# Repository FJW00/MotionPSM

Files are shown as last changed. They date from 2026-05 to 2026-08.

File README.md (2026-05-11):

# MotionPSM

**Mess-System zur Erfassung von Gestängebewegungen an Pflanzenschutzspritzen** auf Basis von Low-Cost GNSS-Modulen (u-blox ZED-F9P, Moving-Base-Konfiguration).

Ursprung: Bachelorarbeit Falk Weigand, Hochschule Weihenstephan-Triesdorf (2025). Weiterentwicklung im Rahmen von FJW Systems.

## Status

- BA-Endstand: Base + 2 Rover, Moving-Base, RTK-fix, Live-Server zur Visualisierung, CSV-Logger mit synchronisierter Zeitstempel-Validierung.
- Aktive Erweiterung (`feature/rover3`): Rover 3 in Fahrtrichtung als geometrische Mittelachsen-Referenz (Base→R3 = Längsachse, R1/R2 als Querauslenkung).
- Zielmeilenstein: DLG-Feldtage 15.06.2026 — System muss 4 Tage am Stück sauber laufen und loggen.

## Struktur

```
MotionPSM/
├── system/
│   ├── pi/                         # Lebender Code (läuft am Raspberry Pi)
│   │   ├── gps_measurement.py      # Threads für Base, Rover1, Rover2 + CSV-Logger
│   │   ├── server.py               # Live-Visualisierung
│   │   └── autostart_schwingung_fw.sh
│   ├── config/
│   │   ├── config.example.json     # Template (echte Datei .gitignored)
│   │   └── f9p_ucenter/            # u-center .txt-Configs für Base/Rover
│   └── analysis/
│       └── Auswertungs_Datei.xlsx  # Prüfprotokoll-Template
├── hardware/                       # STEP/SLDPRT-Modelle Antennenhalterungen, Box
├── documentation/
│   ├── DEVLOG.md                   # Change-Log aller Code-Änderungen
│   ├── 00_initial_meeting.txt      # Auftaktnotizen
│   └── 00_initial_project_vision.md
└── archive/legacy_software/        # Alte Codeversionen, Referenz
```

## Quickstart am Pi

```bash
git clone https://github.com/FJW00/MotionPSM.git
cd MotionPSM
cp system/config/config.example.json system/config/config.json
# COM-Port-IDs eintragen, die zu deiner Hardware passen:
ls /dev/serial/by-id/
# python3-Abhängigkeiten installieren
pip install pyserial pyubx2 pyproj numpy geopy
# Server starten
python3 system/pi/server.py
```

## Hauptmessgröße — Konzept

Bei der bisherigen Setup-Variante (Base + Rover1 + Rover2) wurde das Heading der Base aus deren Eigenbewegung berechnet. Im Stillstand fällt diese Referenz aus, und die Mittellinie ist verrauscht.

Mit Rover 3 vorne in Fahrtrichtung wird der Vektor Base→R3 zur **harten geometrischen Längsachse** der Maschine. Rover 1 und Rover 2 werden senkrecht auf diese Achse projiziert; Ergebnis ist die Querauslenkung des Gestänges in cm — auch im Stillstand stabil.

Details: siehe `documentation/DEVLOG.md` ab Eintrag "Rover3 Mittelachsen-Projektion".

## Verwandte Doku

- `documentation/DEVLOG.md` — alle Änderungen mit Datum + Begründung + offenen Tests
- `archive/legacy_software/` — Vor-Erweiterungs-Codestände (Heading_F9P_thread, alte PI/USB-Varianten)

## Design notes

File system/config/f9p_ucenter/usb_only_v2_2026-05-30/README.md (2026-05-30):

# USB-only Configs für ZED-F9P (Stand 2026-05-30)

## Zweck
Diese Configs lösen das 5-Hz-Problem auf den Rovern: ZED-F9P-Module wurden intern
gedrosselt weil NMEA-Messages auf ALLEN 5 Ports (I2C + UART1 + UART2 + USB + SPI)
gleichzeitig ausgegeben wurden. Bei 10 Hz Mess-Rate × 18 Output-Operationen
landeten effektiv nur 5 Hz NAV-RELPOSNED auf USB.

## Was geändert wurde
Für jedes Modul gegenüber Original:
- USB-Outputs für NMEA-GGA, NMEA-RMC, NMEA-VTG, NAV-RELPOSNED, NAV-PVT: **bleiben aktiv (= 1)**
- I2C, UART1, UART2, SPI Outputs für UBX/NMEA: **auf 0 gesetzt**
- **RTCM-Settings unverändert** (Base UART2-RTCM-Output → Rover Moving-Base-RTK weiterhin funktional)
- CFG-RATE-MEAS = 100 ms (10 Hz) und CFG-RATE-NAV = 1 unverändert

## Wie die korrekten Item-IDs ermittelt wurden
Wichtig: die Item-IDs für jede UBX/NMEA-Message + Port wurden direkt aus
`pyubx2.UBX_CONFIG_DATABASE` extrahiert — autoritative u-blox Doku, identisch
mit der Library die auch der MotionPSM-Logger nutzt.

Ein erster Versuch (Ordner `usb_only_2026-05-25` — wurde verworfen, nicht im Repo)
hatte geschätzte Item-IDs für NAV-RELPOSNED genutzt (offset 0x8C statt 0x8D),
dadurch landete USB auf 0 statt UART2 — Pi konnte kein NAV-RELPOSNED lesen.
Daraus die Lektion: bei UBX-Config-Modifikationen immer pyubx2-DB als Quelle.

## Anwendung in u-center
1. Modul per USB an Laptop
2. Tools → Receiver Configuration → Browse → `..._USBonly_v2.txt`
3. Transfer file → GNSS
4. View → Configuration View → CFG → Save current configuration (BBR + Flash) → Send
5. Disconnect, nächstes Modul

## Verifikation
Auf dem Pi mit pyubx2-Hz-Test:
```bash
sudo systemctl stop motionpsm 2>/dev/null
for port in usb-B_B-if00 usb-R_1-if00 usb-R_2-if00 usb-R_3-if00; do
  echo -n "$port: "
  timeout 5 python3 -c "
import serial,pyubx2,time
s=serial.Serial('/dev/serial/by-id/$port')
u=pyubx2.UBXReader(s,validate=0)
n=0; e=time.time()+5
while time.time()<e:
    try:
        _,p=u.read()
        if p and p.identity in ('NAV-RELPOSNED','NAV-PVT'): n+=1
    except: pass
print(f'{n/5:.1f} Hz')"
done
```
Erwartung: alle Module 10.0 Hz auf NAV-RELPOSNED (Rover) bzw. NAV-PVT (Base).

## Hinweise
- Base-Config liegt vor, ist aber bei Stand 2026-05-30 **noch nicht** geflasht
  (Base war nie der 5-Hz-Engpass, sie lief schon bei vollen 10 Hz).
  Sauberkeitshalber kann sie post-DLG mit dieser Config nachgeflasht werden.
- NAV-PVT USB ist bei den Rovern bewusst aus (war auch in Original-Configs schon so);
  der Logger nutzt NAV-RELPOSNED + die 3 NMEA-Messages.

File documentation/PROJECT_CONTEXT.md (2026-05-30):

# PROJECT_CONTEXT — MotionPSM / FJW Systems

**Diese Datei ist das Cold-Start-Briefing für jede neue Cowork-Session.**
Falk sagt zu Beginn: "Lies erst `documentation/PROJECT_CONTEXT.md`" — und du bist sofort drin.

Stand: 2026-05-30.

---

## Wer und Was

**Person:** Falk-Jakob Weigand, HSWT-Absolvent (Bachelor 2025). Gründer **FJW Systems** (Einzelunternehmen, **angemeldet 20.05.2026** über Bayern-Serviceportal, nicht im Handelsregister eingetragen, Regelbesteuerung). Hauptberuf parallel: Vollzeit-Job Mo–Fr 7–16 Uhr. Codet abends + Wochenenden.

**Gewerbe-Tätigkeitsbeschreibung (Stand 20.05.2026):**

> Entwicklung, Herstellung, Vertrieb, Vermietung und Integration von Mess-, Sensor-, Automatisierungs- und Assistenzsystemen für die Land- und Forstwirtschaft sowie industrielle Anwendungen; Entwicklung, Vertrieb und Betrieb von GNSS-, RTK-, Telemetrie-, IoT- und datenbasierten Systemen; Erbringung von Mess-, Vermessungs-, Analyse- und Monitoringdienstleistungen mittels GNSS-, Sensor-, Drohnen- und Kameratechnologie einschließlich Luftbildauswertung, Vegetationsanalyse sowie Erstellung von Applikations- und Bewirtschaftungskarten für Düngung, Pflanzenschutz und teilflächenspezifische Landwirtschaft; Entwicklung von Hard- und Software, Embedded Systems sowie Datenverarbeitungs- und Cloudlösungen einschließlich Anwendungen im Bereich künstlicher Intelligenz, Automatisierung und Digitalisierung; technische Beratung, Schulung sowie Forschungs- und Entwicklungsdienstleistungen in den genannten Bereichen; Entwicklung, Herstellung und Nachrüstung elektronischer, mechanischer und technischer Komponenten, Sonderlösungen und Prototypen für landwirtschaftliche, kommunale und industrielle Anwendungen; Handel mit Zubehör, Ersatzteilen, elektronischen Baugruppen und technischen Komponenten.

**Produkt:** **MotionPSM** — Low-Cost GNSS-basiertes Mess-System zur Erfassung der Gestängebewegungen von Pflanzenschutzspritzen. Soll Landwirten / Maschinenherstellern eine günstige Möglichkeit geben, Boom-Schwingungen quantitativ zu erfassen.

**Kontakt:**
- Email: falkweigand1304@gmail.com / info@fjw-systems.com
- Domain: fjw-systems.de, fjw-systems.com — **Onepager LIVE seit 30.05.2026** (Impressum + Datenschutz inkl.)
- Firmensitz: Steinig 1a, 97956 Werbach

---

## Hardware-Architektur

- **Base** (u-blox ZED-F9P, C099 Board): zentrale RTK-Basis. **MUSS auf einem starren Rahmen sitzen, NICHT am Gestänge** (sonst werden Rover-Schwingungen systematisch verfälscht — Erkenntnis aus 17.05.-Test). Geeignet: Schlepperdach/Kabine ODER Spritzen-Chassis (sofern lang genug für ~3 m Baseline Base→R3 — Falk's Spritze hat das, getestet 22.05./30.05.). Maximale Sky-View. Sendet RTCM-Korrekturen via UART2 an die Rover.
- **Rover 1** (ZED-F9P): **links** am Gestänge montiert (vom Fahrer aus gesehen).
- **Rover 2** (ZED-F9P): **rechts** am Gestänge.
- **Rover 3** (ZED-F9P): **vorne in Fahrtrichtung am Schlepper** (NICHT am Gestänge), definiert die Längsachse Base→R3.
- **Raspberry Pi 5 (8 GB)**: zentrale Steuerung (seit Ende 2025 von Pi 4 upgegradet). Liest alle Module über USB ein (`/dev/serial/by-id/...`), läuft Flask-Server zur Live-Anzeige + CSV-Logger.
  - **Active Cooler** (GeeekPi Armor Lite V5) seit 30.05.: max. 50°C bei 32°C Außentemperatur + Sonne — Throttling-Problem (87.8°C in alter Box) gelöst.
  - **Neue ASA-Box** mit Belüftungsschlitzen + Heatsink-Aussparung.
- **Antennenhalter**: STEP-Files in `hardware/f9p/`. Falks Eigenkonstruktion mit Kamera-Rohrklemmen — vibrationsfest, wird übernommen für alle Aufbauten.

**RTK-Modus:** Moving-Base. Jeder Rover bekommt RTCM von der Base und liefert `relPosNED` (Position relativ zur Base) mit RTK-Genauigkeit (~cm).

**COM-Port-IDs (echte Werte sind in `system/config/config.json` lokal am Pi, .gitignored):**
- Base: `DBTFR0K9`
- Rover 1: `DBTIHI5H`
- Rover 2: `DBTLN7UC`
- Rover 3: noch nicht festgehalten — beim ersten Anstecken aus `ls /dev/serial/by-id/` ablesen

---

## Mess-Konzept

### Bisher (vor Rover 3)
- Heading der Base aus Eigenbewegung berechnet → verrauscht + nicht stillstandsfähig.
- Moving-Average als Notbehelf für Mittellinien-Stabilisierung.

### Neu mit Rover 3
- Vektor Base→R3 **ist** die geometrische Längsachse der Maschine (auch im Stillstand stabil).
- Zwei parallele Auswertungsvarianten:
  - **Variante A (Hauptmetrik):** R1, R2 senkrecht auf Achse projiziert → `lateral_offset_cm` (signed). Konvention: **links = positiv**, rechts = negativ.
  - **Variante B (Vergleich):** Differenzvektoren R3→R1 und R3→R2 → Distanz + Heading, direkt aus relPosNED-Diff.
- Beides wird ins CSV geloggt (`VarA_*` und `VarB_*` Spalten am Ende).

### CSV-Layout (81 Spalten, Stand 17.05. — unverändert seit Tare/Filter-Iteration)
1. R1 (17 Spalten) — Heading-Stats, Position, Quality
2. R2 (17)
3. R3 (17)
4. Base (8) — Position, Heading, Speed
5. Berechnungen Variante A + B + Achsen-Info + Total (11)
6. Filtered Spalten (6) — Moving-Average longitudinal + Symmetric/Asymmetric Yaw raw+filtered (siehe config.json `FILTER_WINDOW_S`, default 0.2 s)
7. Tare-bereinigte Spalten (5) — VarA_R*_longitudinal/lateral_tared_cm + Tare_set_at

### Hauptmetriken
- **`longitudinal_cm`** = Vor-/Rück-Auslenkung von R1/R2 entlang Fahrtrichtung. + = vorne, − = hinten. **Das ist die Schwingungs-Metrik.**
- **`lateral_cm`** = Seitlicher Abstand zur Längsachse. ≈ Gestängehalbe, fast konstant.
- **`Symmetric Yaw`** = (R2_long − R1_long) / 2. Rotation des Gestänges um die Mittelachse.
- **`Asymmetric Yaw`** = (R1_long + R2_long) / 2. Translation des Gestänges (vor/zurück).
- Mathematik ist **rotationsinvariant gegen Maschinen-Heading** (Beweis im DEVLOG 17.05.).

### UI-Funktionen
- **Tare-Button "⌖ Set Zero"** oben rechts (links neben Toggle): speichert aktuelle Werte als Nullpunkt. CSV bekommt zusätzliche `*_tared_cm`-Spalten. Tare-Status mit Clear-`×` daneben.
- **Toggle "Smoothed | Raw"** oben rechts: schaltet Anzeige zwischen gefilterten und rohen Werten. CSV bekommt immer beides. Persistent in localStorage.
- **Set Zero VOR jeder Messung drücken** (nach Aufbau, Maschine still) → Schwingungs-Auswertung relativ zur Ausgangslage.

---

## Repository-Struktur

```
FJW_Schwingung/                         <- lokaler Master-Ordner
├── MotionPSM_repo/                     <- Git-Repo (github.com/FJW00/MotionPSM)
│   ├── system/
│   │   ├── pi/                         <- Lebender Code
│   │   │   ├── gps_measurement.py      <- Threads, Logger, CSV
│   │   │   ├── geometry.py             <- Mittelachsen-Projektion (Var A) + Diff-Vektoren (Var B)
│   │   │   ├── server.py               <- Flask + HTML-Frontend
│   │   │   └── autostart_schwingung_fw.sh
│   │   ├── config/
│   │   │   ├── config.example.json     <- Template (im Repo)
│   │   │   ├── config.json             <- echte COM-Port-IDs (.gitignored, nur lokal/am Pi)
│   │   │   └── f9p_ucenter/usb_only_v2_2026-05-30/   <- Aktive u-blox Configs (USB-only Outputs, 10 Hz)
│   │   └── analysis/
│   │       └── Auswertungs_Datei.xlsx  <- Excel-Template Prüfprotokoll
│   ├── hardware/                       <- STEP/SLDPRT-Modelle Halter, Box
│   ├── documentation/
│   │   ├── DEVLOG.md                   <- Detail-Log aller Änderungen
│   │   ├── PROJECT_CONTEXT.md          <- DIESE Datei
│   │   ├── 00_initial_meeting.txt
│   │   └── 00_initial_project_vision.md
│   └── archive/legacy_software/        <- alte Code-Stände (Heading_F9P_thread, alte PI/USB-Varianten)
│
├── business/                           <- LOKAL, nie Git
│   ├── branding/                       (Logos)
│   ├── gruendung/{exist,hswt,gewerbeanmeldung}/
│   ├── finanzen/{kalkulationen,rechnungen,steuer}/
│   ├── recht/{ndas,eigentumserklärung}/
│   ├── kunden/feldtage_2026/
│   ├── vorlagen/                       <- Brief/Word-Templates (für Dokumente nutzen)
│   └── website/
│
├── data/                               <- LOKAL, große Files
│   ├── ba_messungen/                   (alte CSVs, Auswertungen)
│   ├── validierung_2025-12/            (Seilzug- und Kamera-Validierung)
│   └── literatur/                      (u-blox-Docs + Fremdliteratur PDFs)
│
├── BA_Abgabe/                          <- Bachelorarbeit, eingefroren read-only
│
└── archive/
    ├── 2026-05-11_full_backup/         (1:1 Backup vor Repo-Reset)
    └── _legacy_empty/                  (leere Original-Ordner, macOS rmdir blockt)
```

---

## Branches

- `main` — **Production-Stand** (54d1dd4): USB-only Configs v2 + Sleep-Fix + alle DEVLOG-Einträge.
- `refactor/logger-itow-dict` — **in Test** (a0fb3f3): Refactor C — iTOW-Dict-Logger statt 4 unsync'd Queues. Behebt die 38%-Sample-Drop-Race in der alten Architektur. Bench-Test am Pi am 31.05.2026, bei Erfolg Merge nach main.
- `refactor/cleanup` — historischer Branch (Stufe-2-Refactor), unverändert seit Mai
- `feature/rover3` — gelöscht (komplett in main gemerged, 30.05.)

---

## Termine + Meilensteine — laufender Fortschritt

| Datum | Was | Status |
|---|---|---|
| 14.05. | Bench-Test Rover 3 | ✅ |
| 15.–17.05. | Feldtest + Iterationen, UI-Refactor, Filter, Tare | ✅ |
| 19.05. | Steuerberater-Termin | ✅ |
| 20.05. | **Gewerbeanmeldung** Bayern-Serviceportal | ✅ Gründungstag |
| 22.05. | Testfahrt mit Tare: 10 cm Stand-Auslenkung exakt gemessen | ✅ (Geometrie + Tare validiert) |
| 22.05. | Pi-Thermal-Problem entdeckt (87.8°C → Sample-Lücken) | ✅ diagnostiziert |
| 23.05. | Active Cooler bestellt (GeeekPi Armor Lite V5) | ✅ |
| 24./25.05. | Generalprobe-Wochenende mit neuer Box + Cooler (50°C bei 32°C/Sonne) | ✅ |
| 25.05. | 5-Hz-Problem entdeckt (CFG-RATE OK aber NMEA-Multicast drosselt F9P) | ✅ diagnostiziert |
| 26.05. | USB-only Configs v1 — fehlerhaft (off-by-one Item-IDs) | ✅ verworfen |
| 30.05. | USB-only Configs v2 mit pyubx2-DB → 10 Hz auf allen Modulen | ✅ commit 54d1dd4 |
| 30.05. | Hof-Test: 10/20 cm Tare-Auslenkung exakt gemessen | ✅ Geometrie 2× validiert |
| 30.05. | Logger-Refactor C (iTOW-Dict) implementiert | ✅ commit a0fb3f3 (Branch) |
| 30.05. | Grundplatten Base + R3 bestellt | ✅ |
| 30.05. | feature/rover3 → main gemerged, Repo aufgeräumt | ✅ |
| 30.05. | **fjw-systems.de LIVE** (Impressum + Datenschutz) | ✅ 🎉 |
| **31.05. 09:00** | **Bench-Test Refactor C am Pi** | 📅 scheduled |
| Anfang Juni | Echte Testfahrt mit Refactor + USB-only + Hardware-Updates | ⏳ |
| Anfang Juni | ZTE-WLAN-Port-Forwarding fixen (Tablet↔Pi externer Zugang) | ⏳ |
| Anfang Juni | Autostart am Pi aktivieren (`install_autostart.sh`) | ⏳ |
| 06./07.06. | Reserve-WE für letzte Fahrtests + Bug-Fix | herabgestuft |
| Vor 15.06. | Geschäftskonto eröffnet | ⏳ (nicht zwingend) |
| **15.–18.06.** | **DLG-Feldtage Bernburg** — erste öffentliche Demo | Hauptevent |
| Juli 2026 | GitHub-PAT von Classic auf Fine-grained rotieren (läuft August aus) | 📅 |
| Nach 15.06. | RTCM-Löten, Cloudflare-Tunnel (`measure1.fjw-systems.com`), Pi-User/Hostname-Migration | später |

---

## Konventionen / Falk's Präferenzen

- **Sprache:** Deutsch.
- **Tonalität:** pragmatisch, direkt, keine Floskeln.
- **Vor destruktiven Änderungen fragen** ("wenn du änderungen machst frage mich").
- **DEVLOG parallel führen** — jeder Code-Change kriegt einen Eintrag mit Was/Warum/Test offen/Risiko.
- **Vertrauliche Daten niemals ins Repo:** echte HW-IDs, NDAs, Kalkulationen, Förderanträge gehören in `business/` oder werden sanitisiert.
- **Calendar:** noch nicht freigeschaltet. Steuerberater (Freund) kümmert sich Falk selbst.

---

## Tech-Stack

- **Python 3** (Pi 5, venv): Flask, pyserial, pyubx2, pyproj, numpy, geopy
- **Frontend:** Vanilla HTML + Chart.js (CDN)
- **GNSS:** u-blox ZED-F9P, Moving-Base, **10 Hz** (effektiv erreicht nach USB-only Configs v2 + Refactor C). Baudrate 460800 auf USB.
- **LTE-Konnektivität:** ZTE-WLAN-Stick + Thingsmobile IoT-SIM in der Box (für DLG-Stand-WLAN; Port-Forwarding für externen Zugriff noch zu fixen)
- **Datenformat:** CSV mit `;`-Separator und `,`-Decimal (Excel-DE-kompatibel)

---

## Offene Punkte / Ideen für später

**Vor DLG (15.06.):**
- **Bench-Test Refactor C** (31.05. 09:00 scheduled): wenn >95% iTOW-Lücken bei 100 ms → Merge nach main
- **ZTE-WLAN-Port-Forwarding**: WLAN-Verbindung Tablet↔Pi funktioniert, aber externer Port (Remote-Zugriff aufs Frontend) klemmt. ZTE-Admin-Interface checken.
- **Autostart am Pi aktivieren** (`bash system/pi/install_autostart.sh`) — Code liegt schon, war für "nach Generalprobe" geplant, jetzt der richtige Moment
- **Echte Testfahrt** mit allen Updates zusammen (Refactor C + USB-only + Box + Cooler)

**Nach DLG:**
- **Remote-Zugriff `measure1.fjw-systems.com`** — Cloudflare-Tunnel (braucht Nameserver-Umstellung weg von Strato) ODER Pi-eigener WLAN-AP als Fallback
- **Pi-User + Hostname migrieren** — derzeit User `ba_weigand`, Hostname `BA_Weigand` aus der BA-Zeit. Sauberer wäre `motionpsm` + `motionpsm-pi-01`
- **Base-Config mit USBonly_v2 nachflashen** — war beim 5-Hz-Fix nicht zwingend (Base war nicht der Engpass), nur für Konsistenz
- **NumSV / HDOP / accHeading** im Frontend zeigen
- **GitHub-PAT** von Classic auf Fine-grained umstellen (Sicherheit)
- **Mail-/Kalender-MCP** (Google Workspace) — Cowork-Connector

## Hardware-Detail: udev-Regeln am Pi

Falk hat udev-Regeln eingerichtet, die die F9P-Module unter festen Kurz-Namen mappen (Pi-User noch `ba_weigand` aus BA-Zeit, Migration post-DLG geplant):
- `/dev/serial/by-id/usb-B_B-if00` (Base)
- `/dev/serial/by-id/usb-R_1-if00` (Rover 1, links)
- `/dev/serial/by-id/usb-R_2-if00` (Rover 2, rechts)
- `/dev/serial/by-id/usb-R_3-if00` (Rover 3, vorne)

Diese Namen kommen in seine echte `system/config/config.json` (.gitignored). Die `config.example.json` im Repo hat die langen Standard-IDs als Platzhalter.

---

## Wie ich (Claude) helfe

- Code-Änderungen: erst Diff zeigen, dann committen, dann pushen.
- Bei langen Tasks: TodoList + Backup vor destruktiven Schritten.
- Push erfolgt via PAT (im August 2026 auslaufend); Token bei Bedarf erneuern.
- Branches: pro Feature ein eigener Branch, Push auf GitHub, Merge per Falk-Entscheidung.
- Bei neuer Session: bitte dieses File lesen, dann letzten DEVLOG-Eintrag, dann `git log --oneline -10` für aktuellen Repo-Stand.

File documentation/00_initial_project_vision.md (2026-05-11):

# BA_Weigand

# Erfassung von Schwingungen im Spritzengestänge durch Low-Cost Messsystem

## Projektübersicht
Dieses Projekt zielt darauf ab, ein kostengünstiges und modulares System zu entwickeln, das die Schwingungen von Spritzgestängen in der Landwirtschaft erfasst. Die erfassten Daten sollen gespeichert und zur Optimierung von Precision-Farming-Anwendungen genutzt werden.

## Zielsetzung
- **Modularität**: Flexible Anpassung an verschiedene Spritzgestänge und Sensoren.
- **Datenerfassung und -speicherung**: Aufzeichnung der Messdaten auf einer SD-Karte.
- **Analyse der Schwingungen**: Berechnung der Schwingungsdaten relativ zur Gesamtbreite des Gestänges.

## Systemansätze
Es werden drei mögliche Ansätze untersucht, wobei die ersten beiden priorisiert werden:

1. **GNSS-Modul (F9P)**:
   - Verwendung von 3-4 GNSS-Empfängern:
     - Zwei Empfänger in der Mitte des Gestänges zur Bestimmung von Heading und Offset.
     - Jeweils ein Empfänger an den Enden zur Detektion der Schwingungen.
   - **Offene Fragen**: Konfiguration und serielle Kommunikation.

2. **Beschleunigungssensoren**:
   - Platzierung von Sensoren an den Enden und in der Mitte des Gestänges.
   - Messung der Beschleunigungen zur Analyse der Schwingungen.
   - **Offene Fragen**: Nutzung von Interrupts oder Dataloggern.

3. **Kamerabasierte Lösung (OpenCV)**:
   - Kamera in der Mitte des Gestänges, die zwei markierte Bälle an den Enden verfolgt.
   - Analyse der Ballbewegung zur Erkennung von Schwingungen.
   - **Herausforderung**: Hoher Umsetzungsaufwand, daher aktuell nicht priorisiert.

## Anforderungen
- **Modularität**: Das System muss einfach erweiterbar sein.
- **Datenaufzeichnung**: Speicherung aller relevanten Daten auf einer SD-Karte.
- **Prozentuale Analyse**: Berechnung der Schwingungen relativ zur Breite des Gestänges.

## Vorgehensweise
1. **Entwicklung der Testsysteme**:
   - Umsetzung der Ansätze mit GNSS-Modulen und Beschleunigungssensoren.
2. **Validierung und Tests**:
   - Durchführung von Tests an der Landwirtschaftlichen Lehranstalt (LLA) mit Spritzgestängen verschiedener Hersteller.
   - Kalibrierung der Sensoren durch Vergleich mit Bodenmessungen (z. B. Meterstab oder Skala).

## Offene Fragen
Während des Projekts sind folgende Punkte zu klären:
- Wie können Korrekturdaten effizient verteilt werden?
- Ist eine Berechnung über den Dopplereffekt sinnvoll?
- Welche bestehenden Systeme können als Referenz dienen?
- Welcher Ansatz ist am zuverlässigsten, kostengünstigsten und genauesten?

## Motivation
Das Projekt unterstützt die Weiterentwicklung des Precision Farming, indem es präzisere Daten für die Optimierung von Spritzgestängen liefert. Dies trägt zur Effizienzsteigerung und Ressourcenschonung in der Landwirtschaft bei.

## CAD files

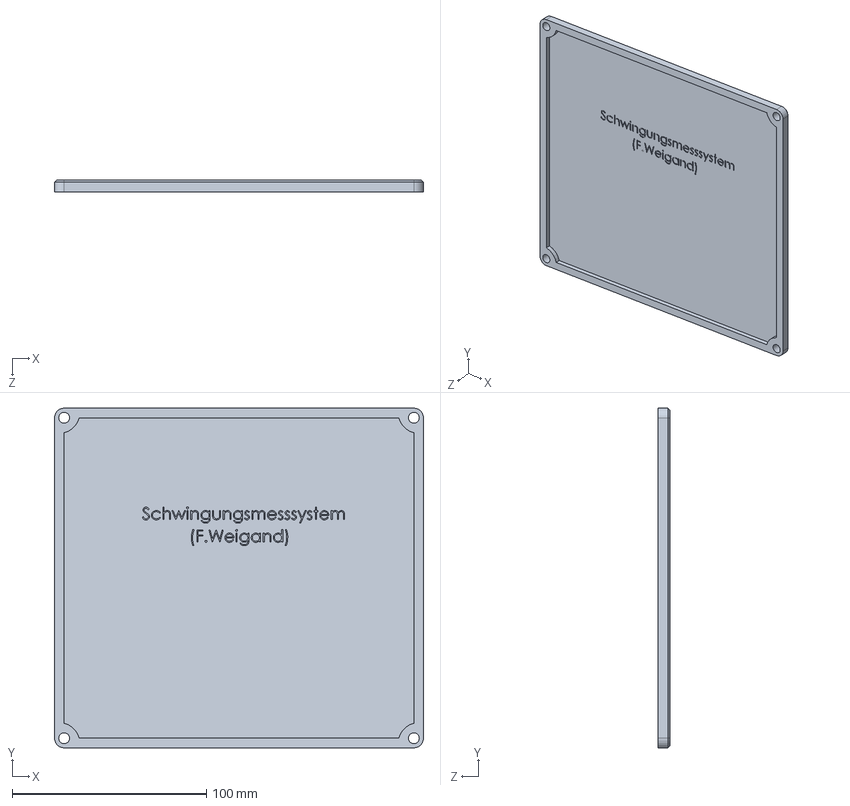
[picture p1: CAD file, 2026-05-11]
hardware/f9p/C099-F9P/Deckel.SLDPRT
190.0 x 175.0 x 6.00 mm

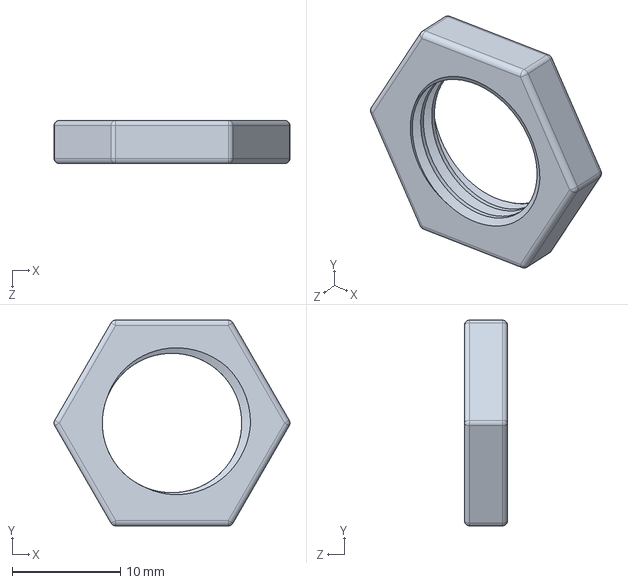
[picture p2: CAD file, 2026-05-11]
hardware/f9p/Mutter_M16x1,5.STEP
21.8 x 19.0 x 4.00 mm

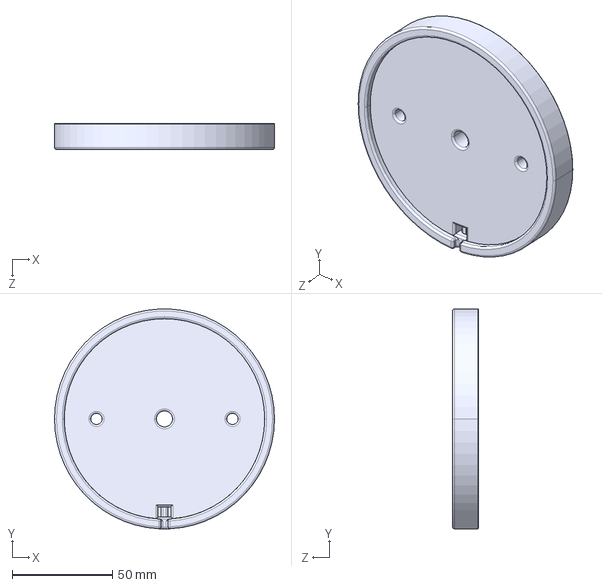
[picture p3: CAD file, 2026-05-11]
hardware/f9p/ANN-MB_holder_v3.STEP
110.0 x 109.9 x 13.0 mm

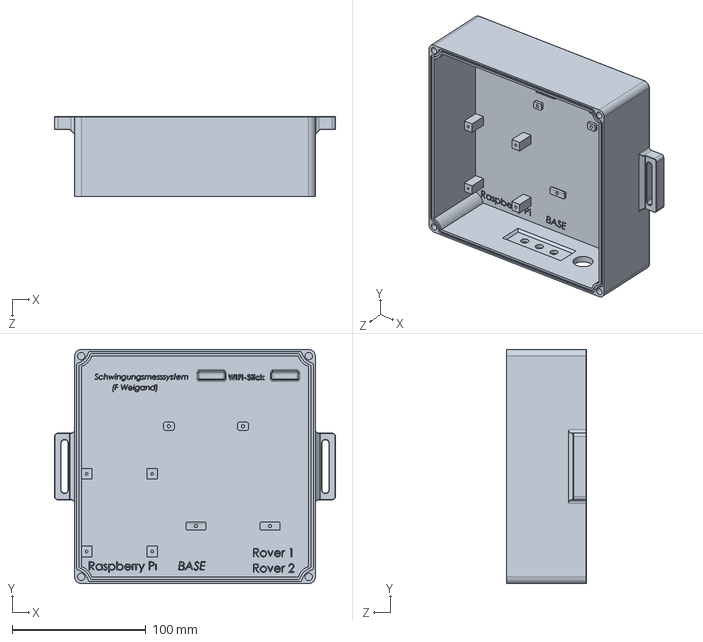
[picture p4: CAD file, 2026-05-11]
hardware/f9p/Ardusimpel_F9P/BOX_v4.SLDPRT
210.0 x 175.0 x 60.0 mm

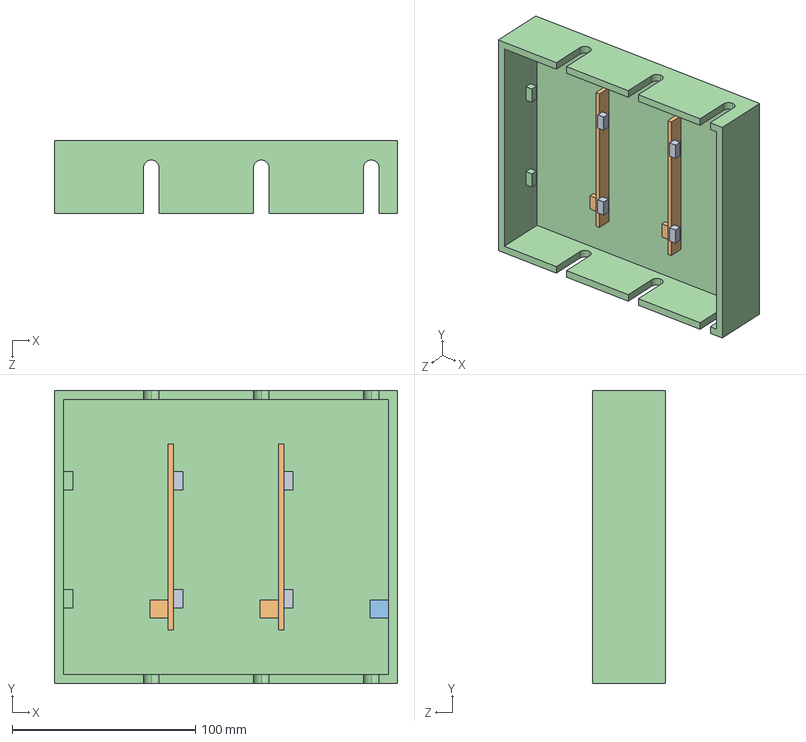
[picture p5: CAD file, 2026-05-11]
hardware/f9p/C099-F9P/BOX.STEP
187.0 x 160.0 x 40.0 mm

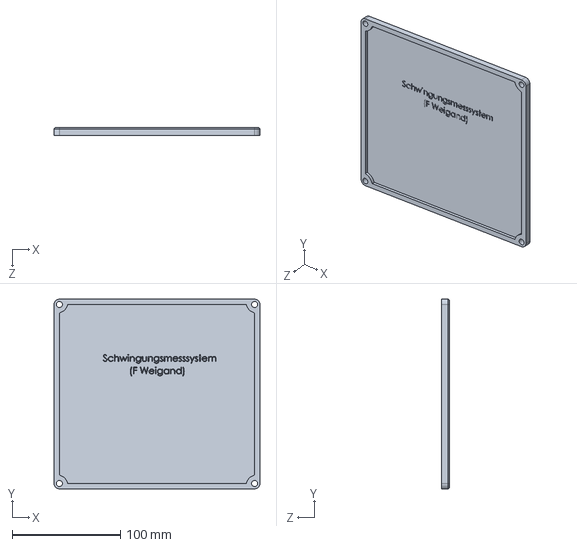
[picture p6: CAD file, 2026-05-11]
hardware/f9p/Ardusimpel_F9P/Deckel.SLDPRT
190.0 x 175.0 x 7.00 mm

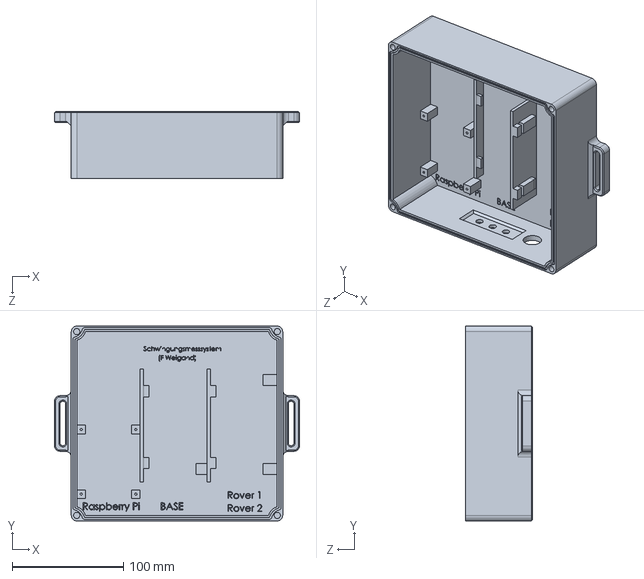
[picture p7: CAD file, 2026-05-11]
hardware/f9p/C099-F9P/BOX_v3.SLDPRT
220.0 x 175.0 x 60.0 mm

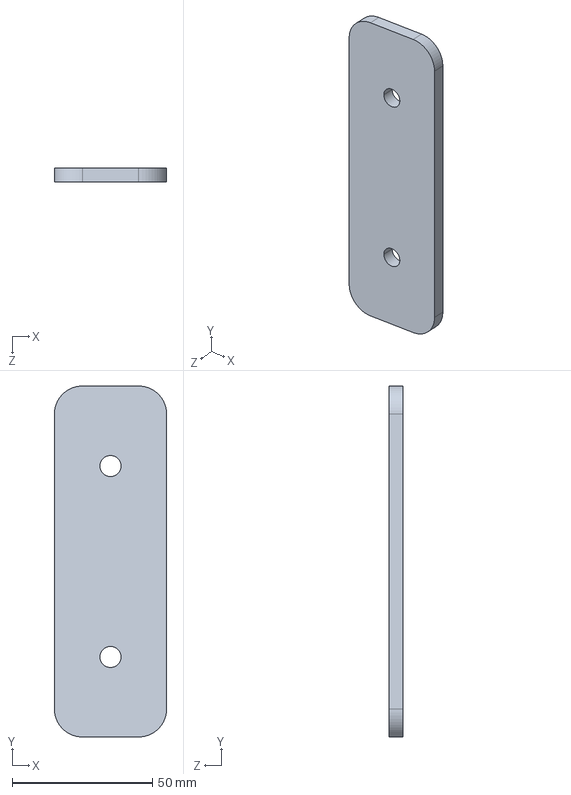
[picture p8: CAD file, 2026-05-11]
hardware/f9p/Klemmung_v1.STEP
40.0 x 125.0 x 5.00 mm

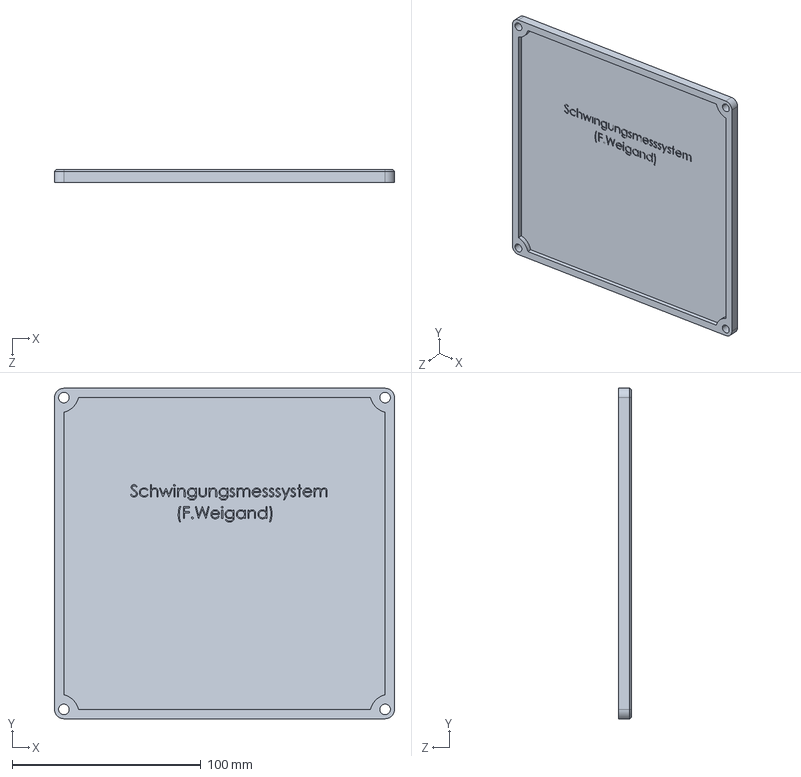
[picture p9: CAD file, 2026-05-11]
hardware/f9p/Ardusimpel_F9P/Deckel_v3.STEP
180.0 x 175.0 x 7.00 mm

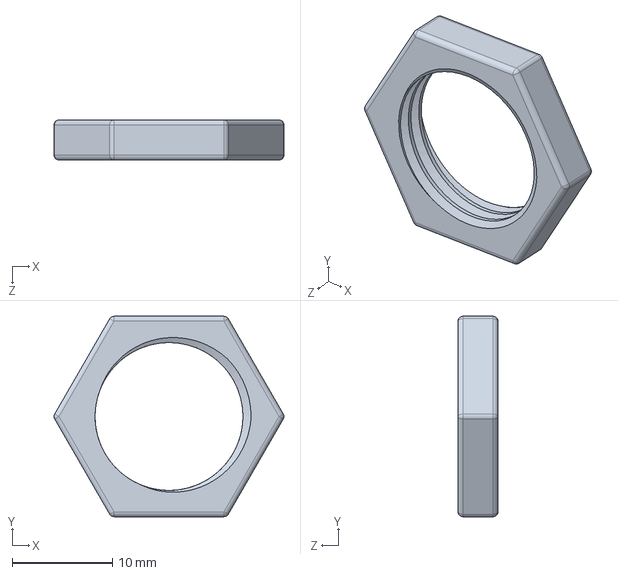
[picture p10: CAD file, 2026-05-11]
hardware/f9p/Mutter_M18x1,5.STEP
22.9 x 20.0 x 4.00 mm

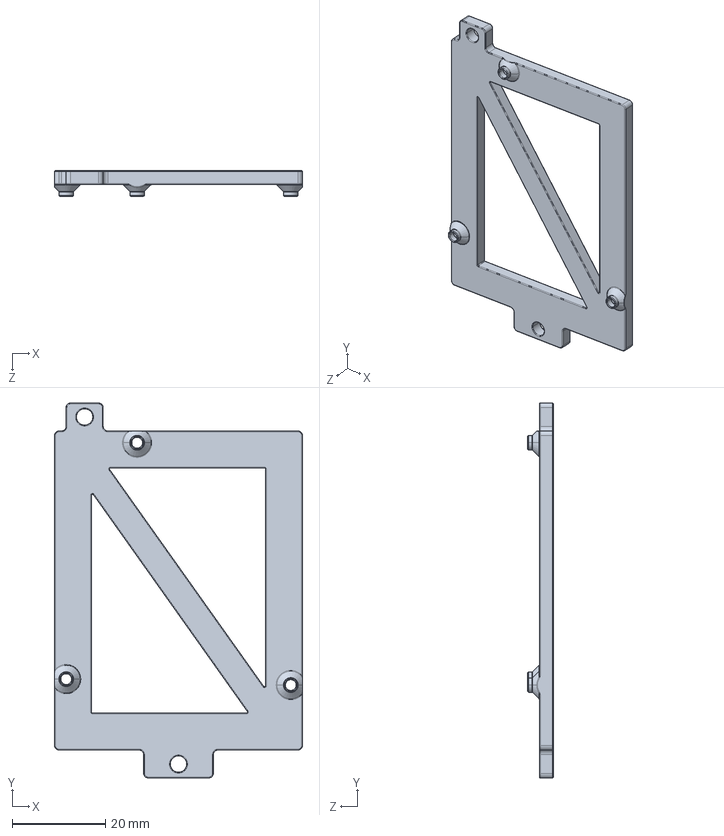
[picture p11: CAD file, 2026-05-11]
hardware/f9p/Ardusimpel_F9P/F9P_Halter.STEP
53.3 x 80.6 x 5.50 mm

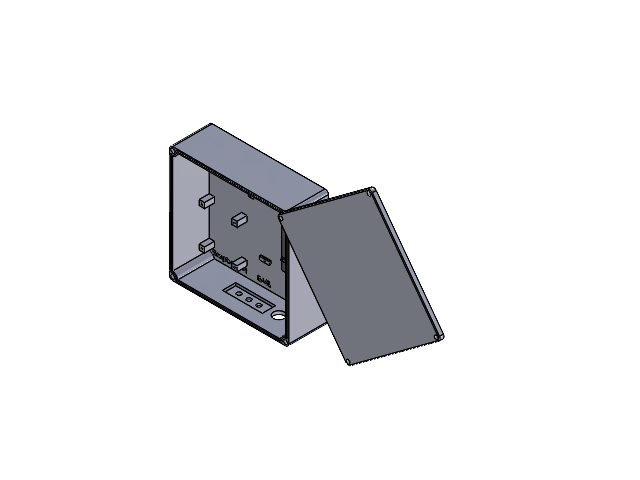
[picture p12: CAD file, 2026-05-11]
hardware/f9p/Ardusimpel_F9P/BOX_Komplett.SLDASM
BOX_v4
F9P_Halter
Deckel_v2

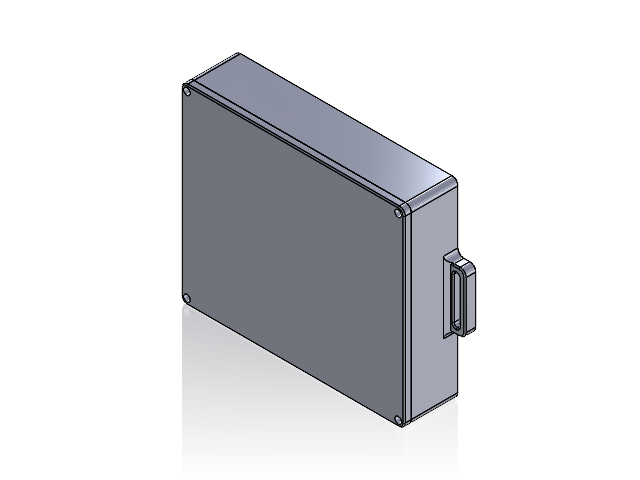
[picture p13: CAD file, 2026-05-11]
hardware/f9p/C099-F9P/BOX_Komplett.SLDASM
Deckel

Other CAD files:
hardware/f9p/C099-F9P/Deckel_v2.STEP
hardware/f9p/ANN-MB_holder.STEP
hardware/f9p/Ardusimpel_F9P/simpleRTK2B.SLDPRT
hardware/f9p/ANN-MB_holder_v2.STEP
hardware/f9p/ANN-MB_holder.SLDPRT
hardware/f9p/ANN-MB_holder_v2.SLDPRT
hardware/f9p/ANN-MB_holder_v3.SLDPRT
hardware/f9p/Ardusimpel_F9P/Deckel_v2.SLDPRT
hardware/f9p/Ardusimpel_F9P/Deckel_v2.STEP
hardware/f9p/Ardusimpel_F9P/Deckel_v3.SLDPRT
hardware/f9p/Ardusimpel_F9P/F9P_Halter.SLDPRT
hardware/f9p/Ardusimpel_F9P/simpleRTK2B.STL
hardware/f9p/C099-F9P/BOX.SLDPRT
hardware/f9p/C099-F9P/Deckel_v1.STEP
hardware/f9p/Klemmung_v1.SLDPRT
hardware/f9p/Mutter_M18x1,5.SLDPRT

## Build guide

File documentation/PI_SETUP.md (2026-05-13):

# MotionPSM — Pi-Setup

Schritt-für-Schritt-Anleitung zum Einrichten von MotionPSM auf einem Raspberry Pi (frischer Zustand).

Annahme: Raspberry Pi mit aktuellem Pi-OS (Bookworm oder neuer), Internet-Verbindung, SSH oder direkter Login.

---

## 0. Vorbereitung

Du brauchst:
- Raspberry Pi 4 (oder neuer) mit aktuellem Pi-OS
- Internet-Verbindung
- Alle 4 F9P-Module per USB angesteckt (Base + R1 + R2 + R3)
- Basis-Konfiguration via u-center am PC einmal aufgespielt (Configs in `system/config/f9p_ucenter/`)

---

## 1. Repository klonen

```bash
cd ~
git clone https://github.com/FJW00/MotionPSM.git
cd MotionPSM
git checkout feature/rover3      # oder refactor/cleanup für Stufe-2-Variante
```

---

## 2. Setup ausführen

```bash
bash system/pi/setup_pi.sh
```

Was passiert dabei:
- System-Pakete prüfen (python3-venv, git, pip) und falls nötig installieren — `sudo` wird abgefragt
- venv anlegen unter `~/MotionPSM/.venv/`
- Python-Abhängigkeiten aus `requirements.txt` installieren (flask, pyserial, pyubx2, pyproj, numpy, geopy)
- `system/config/config.json` aus Template kopieren (falls noch nicht da)

Dauert ca. 2-5 Minuten je nach Pi-Leistung und Internet.

---

## 3. COM-Port-IDs eintragen

Stelle sicher, dass **alle vier F9P-Module per USB gesteckt** sind, dann:

```bash
ls /dev/serial/by-id/
```

Beispiel-Output:
```
usb-u-blox_AG_C099__ZED-F9P_DBTFR0K9-if00-port0
usb-u-blox_AG_C099__ZED-F9P_DBTIHI5H-if00-port0
usb-u-blox_AG_C099__ZED-F9P_DBTLN7UC-if00-port0
usb-u-blox_AG_C099__ZED-F9P_<NEUE-R3-ID>-if00-port0
```

Die letzten 8 Zeichen vor `-if00-port0` sind die ID jedes Moduls. **Beschrifte deine Module physisch** (Sticker am Gehäuse), damit du weißt: welche ID ist Base, R1, R2, R3?

Dann editieren:

```bash
nano ~/MotionPSM/system/config/config.json
```

Eintragen:
```json
{
  "BASE_COM_PORT":   "/dev/serial/by-id/usb-u-blox_AG_C099__ZED-F9P_DBTFR0K9-if00-port0",
  "ROVER1_COM_PORT": "/dev/serial/by-id/usb-u-blox_AG_C099__ZED-F9P_DBTIHI5H-if00-port0",
  "ROVER2_COM_PORT": "/dev/serial/by-id/usb-u-blox_AG_C099__ZED-F9P_DBTLN7UC-if00-port0",
  "ROVER3_COM_PORT": "/dev/serial/by-id/usb-u-blox_AG_C099__ZED-F9P_<R3-ID>-if00-port0",
  "LIVE_PLOT": true
}
```

**Wichtig:**
- R1 = **links** am Gestänge montiert
- R2 = **rechts** am Gestänge
- R3 = **vorne** in Fahrtrichtung

Falls du dir bei R1/R2 unsicher bist: ein Probelauf, dann in der Live-Visualisierung schauen. Wenn die R1-Auslenkung beim Linkslenken negativ statt positiv ist, IDs in der config einfach tauschen.

---

## 4. Erster Test (manuell)

Vor dem Autostart erstmal manuell prüfen:

```bash
cd ~/MotionPSM
source .venv/bin/activate
python3 system/pi/server.py
```

Im Browser auf einem anderen Gerät (Handy/Tablet/Laptop im selben WLAN):

```
http://<pi-ip>:5000
```

Pi-IP findest du mit `hostname -I`.

**Was du sehen solltest:**
- Hauptseite mit Button "Messung starten"
- Nach Klick: Hero-Layout mit SVG-Gestänge, Quality-Boxen
- Wenn alle 4 Module RTK Fix haben (grün), bewegen sich die Werte realistisch (im Stand: lateral_cm sollte stabil bleiben, axis_length sollte der physischen Distanz Base→R3 entsprechen, z.B. 2-3m)

Strg+C zum Stoppen.

---

## 5. Autostart einrichten

```bash
bash system/pi/install_autostart.sh
```

Was passiert:
- Service-Template wird mit deinem User + Repo-Pfad gerendert
- Nach `/etc/systemd/system/motionpsm.service` kopiert (sudo)
- `systemctl enable` damit beim Boot startet

Sofort starten zum Testen:

```bash
sudo systemctl start motionpsm
sudo systemctl status motionpsm
```

Logs verfolgen:

```bash
sudo journalctl -u motionpsm -f
```

---

## 6. Nach Reboot prüfen

```bash
sudo reboot
```

Nach Neustart ssh-back rein und prüfen:

```bash
sudo systemctl status motionpsm
```

Sollte `active (running)` zeigen. Wenn nicht: `journalctl` lesen, sehr wahrscheinlich falsche COM-Port-ID in config.json oder einer der Module nicht gesteckt.

---

## Häufige Probleme

| Symptom | Ursache | Lösung |
|---|---|---|
| `FEHLER: config.json fehlt` | Schritt 3 übersprungen | `cp config.example.json config.json` |
| `Could not open port /dev/...` | COM-Port-ID falsch oder Modul nicht gesteckt | `ls /dev/serial/by-id/` prüfen, IDs vergleichen |
| Service startet aber crashed | venv-Probleme oder fehlende Deps | `journalctl -u motionpsm -n 100` lesen |
| Keine Daten im Frontend, Charts leer | Module noch beim Initialisieren / kein RTK-Fix | 1-2 Min warten, Quality-Badge prüfen |
| `RuntimeError: Fehlende Config-Felder` | ROVER3_COM_PORT vergessen | config.json prüfen |
| Pi reagiert langsam | Logger-Thread spammt CSV | `sudo systemctl restart motionpsm`, CSVs in `/tmp/` aufräumen |

---

## Update auf neuere Code-Version

Wenn neue Commits gepusht werden:

```bash
cd ~/MotionPSM
sudo systemctl stop motionpsm
git pull
# Falls requirements.txt sich geändert hat:
source .venv/bin/activate
pip install -r system/pi/requirements.txt
deactivate
sudo systemctl start motionpsm
```

Branch wechseln (z.B. von `feature/rover3` zu `refactor/cleanup`):

```bash
sudo systemctl stop motionpsm
git fetch
git checkout refactor/cleanup
sudo systemctl start motionpsm
```

---

## Backup

Wichtige Datei: `system/config/config.json` (deine echten COM-Port-IDs).
Sicherheitskopie irgendwo ablegen, falls Pi-SD-Karte mal ausfällt.

CSVs landen in `/tmp/` — sind beim Reboot weg! Direkt nach jeder Aufnahme über das Frontend `CSV exportieren` drücken und sicher ablegen.

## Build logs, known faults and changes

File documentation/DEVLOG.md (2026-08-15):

# DEVLOG

Detail-Log aller Änderungen am MotionPSM-System. Neueste Einträge oben.

---

## 2026-08-15 — Live-Degradation: Kandidat 2 (Thermik) ausgeschlossen, nächster Test vorbereitet

**Kandidat 2 (thermische Pi-Drosselung) ausgeschlossen — Falks Gegenargument:** War nicht heiß am 14.08., und wichtiger: ein CFG-RST-Reset am F9P-Modul kann die Pi-CPU-Temperatur/-Drosselung gar nicht beeinflussen. Dass der Reset zuverlässig sofort wieder 10Hz bringt, beweist, dass die Ursache am F9P/USB-Pfad hängt, nicht an allgemeiner Pi-Rechenlast/Hitze. Sauberer Ausschluss, nicht nur Bauchgefühl.

**Falk hat außerdem die USB-Strom-Drosselung am Pi (Throttling bei zu hoher Stromaufnahme über die USB-Ports) deaktiviert.** Für später als Idee notiert, aber nicht akut: F9P-Module ggf. direkt über eigene 5V-Versorgung statt über Pi-USB-Strom versorgen, falls Strom weiterhin ein Thema wird.

**Verbleibende Kandidaten für die Live-Degradation während einer laufenden Messung** (Sammlung aus Falks und meinen Ideen):
- GIL-Kontention Flask vs. Producer-Threads mit sich aufschaukelndem Rückstau (Puffer/Backlog wächst statt sich einzupendeln)
- Pi drosselt USB-Geschwindigkeit unter Last (unabhängig von der jetzt deaktivierten Strom-Drosselung — ggf. Bandbreiten-/Scheduling-Ebene)
- F9P-interner Sende-Puffer läuft voll, wenn Host nicht schnell genug abholt (Falk hält das für unwahrscheinlich)
- Moving-Base fürs Senden an 1 Rover ausgelegt, jetzt an 3 gleichzeitig — vermutlich kein Faktor, da RTCM-Output vermutlich als Broadcast auf UART2 läuft (ein Sendevorgang, mehrere passive Hörer), nicht pro Rover einzeln dupliziert — müsste aber verifiziert werden, nicht nur angenommen.
- USB-Verbindung/Controller am Pi generell (Hub-Bandbreite, Scheduling)

**Nächster Test (vorbereitet, noch nicht ausgeführt):** 4 Module **gleichzeitig, aber komplett unabhängig von `gps_measurement.py`/Flask** auslesen — 4 separate Python-Prozesse parallel für 60s (kein gemeinsamer GIL, kein Flask-Polling), Wall-Clock-Zeit + iTOW pro Sample in JSON loggen. Soll trennen zwischen:
- Degradation tritt AUCH hier auf → Ursache liegt auf USB/Hardware-Ebene (Pi-Controller, F9P-Verhalten unter 4-fach-Last), unabhängig vom Python-Code.
- Bleibt sauber bei 10Hz → Ursache ist spezifisch an der `gps_measurement.py`/Flask-Architektur festzumachen (GIL/Threading).

Skript-Vorlage liegt im Chat-Verlauf bereit (4 parallele `python3 -c`-Hintergrundprozesse, einer pro Modul, `wait` am Ende, JSON-Output nach `/tmp/hz_parallel_test/`).

**Test offen:** Hoftest-Aufbau + paralleler Test stehen noch aus (Falk ist heute an was anderem dran, macht das, sobald der Hoftest wieder steht).

---

## 2026-08-14 (Fortsetzung 3) — CFG-RST-Reset auf alle 4 Module + End-to-End-Test: weiterhin NEGATIV

**Was:** UBX-CFG-RST (Hardware-Reset, Hot-Start) auf alle 4 Module (Base, R1, R2, R3) angewendet, einzeln verifiziert (siehe unten), danach `systemctl start motionpsm` und echte Messung über die Web-UI (Set Zero → Start → ~60s → Stop → Export). 2 CSVs unter `~/Documents/FJW_Schwingung/Records/CSV/20260814/`.

**Einzel-Verifikation der Rover nach Reset (vor der eigentlichen Messung):** R1/R2/R3 lagen vor dem Reset alle bei ~4.6-4.7 Hz (200ms-Boden, festgefahren aus den vielen Tests/Start-Stops des Tages). Nach CFG-RST-Reset + Wartezeit: wenn Daten kamen, ~9.9 Hz (82×100ms + 12×200ms) — deutliche Verbesserung, nicht perfekt. Vereinzelt 0 Samples in den ersten Verifikationsversuchen direkt nach Reset (`Port wieder offen` aber 0 NAV-RELPOSNED in 10s) — plausibel durch RTK-Ambiguitäts-Neuaufbau nach Hardware-Reset, der laenger dauert als der reine Port-Reconnect; begleitet von "Unknown protocol header"-Meldungen (Frame-Muell waehrend des Modul-Neustarts, erwartbar, kein eigenstaendiger Bug).

**End-to-End-Ergebnis trotzdem negativ:**

| Datei | Dauer | Median dt | ≤100ms | eff. Rate | Sync-Mismatches |
|---|---|---|---|---|---|
| 194005 | 61s | 200ms | 0.0% | 4.22 Hz | 0 |
| 194233 | 60s | 200ms | 19.5% | 3.31 Hz | 0 |

Sync weiterhin perfekt (0 Mismatches R1/R2/R3/Base) — bestätigt erneut, dass der Logger nicht die Ursache ist.

**Korrektur nach genauerem Blick auf den zeitlichen Verlauf (nicht nur die aggregierte Verteilung) — Falk hat zu Recht nachgehakt:**

- **194005** (mit mehr Zwischenschritten zwischen Reset und Start): von Sample 0 an nie 100ms, durchgehend 200/500ms im Wechsel.
- **194233** (laut Falk: direkt nach Restart, ohne Pause, sofort UI → Start): **die ersten 8 Samples laufen exakt bei 100ms** — sauberer 10-Hz-Start, bestätigt dass ein wirklich unmittelbarer Reset→Start-Übergang funktioniert. Danach kippt es aber **progressiv während der laufenden Messung**: ab ca. Sample 60 (~10-12s Messdauer) dominiert 200ms, ab Sample ~140 kommen zunehmend große Aussetzer (500-2200ms) dazu.

**Das heißt: zwei unterschiedliche, sich überlagernde Mechanismen, nicht einer:**
1. **Vor-Start-Degradation** (bereits bekannt): Zwischenschritte/Verzögerung zwischen Reset und Messstart verschlechtern die Startqualität (194005 vs. 194233).
2. **NEU — Live-Degradation während der Messung selbst:** Selbst mit sauberem 100ms-Start baut sich die Rate innerhalb der 60s-Messung progressiv ab. Das konnten die bisherigen Isolationstests nie zeigen, weil die immer nur 10s mit einem einzelnen Thread liefen, nie 60s mit dem vollen System (4 Threads + Flask-Polling durch den Browser alle 100ms). Das deutet wieder Richtung der alten GIL/Flask-Polling-Konkurrenz-Theorie aus dem Juni 2026 — zusätzlich zur F9P-internen Akkumulation, die heute isoliert nachgewiesen wurde.

**Schlussfolgerung für heute:** Ein einmaliger Reset zu Sessionbeginn reicht nicht — weder gegen die Vor-Start-Degradation (braucht Reset unmittelbar vor jedem Start) noch gegen die Live-Degradation während der Messung (das ist ein anderes, noch ungeklärtes Thema, vermutlich GIL/Threading-bezogen, nicht F9P-Hardware).

**Nicht heute umgesetzt** (Falk wollte für heute Schluss machen) — Code-Änderungen erst nach Rücksprache, siehe Standing Rule #4 (Approval vor größeren Änderungen).

**Test offen (zwei getrennte Baustellen für nächstes Mal):**
1. **Vor-Start-Degradation:** CFG-RST-Reset direkt in `start_measurement()` integrieren (eigener Branch, nicht auf `fix/reader-once-per-thread`), mit Wartezeit auf RTK-Fix statt fixem Sleep.
2. **Live-Degradation während der Messung:** eigene Diagnose nötig — z.B. dt-Verlauf über die Zeit in einer 60s-Messung mit `top`/CPU-Last parallel beobachten, ob GIL-Kontention (Flask-Polling vs. Producer-Threads) zeitlich mit dem Abfall korreliert. Nicht mit Schritt 1 verwechseln, vermutlich unabhängige Ursache.
3. Branch `fix/reader-once-per-thread` bleibt weiterhin ungemergt, `main` weiterhin auf `v1.0-dlg`.

---

## 2026-08-14 (Fortsetzung 2) — Akkumulation lokalisiert: F9P-intern, nicht Pi/Kernel/Python

*(Datums-Korrektur: dieser und die beiden folgenden Einträge waren ursprünglich fälschlich auf 05.08. datiert — Standing Rule #1 nicht befolgt, Datum nicht neu geprüft nach Session-Sprung. Tatsächliches Datum laut Systemzeit + CSV-Timestamps: 14.08.2026. Zwischen dem Hoftest vom 05.08. und dieser Diagnose-Session lagen also 9 Tage.)*

**Testreihe (Falk, isolierter Base-Test, mehrere aufeinanderfolgende `python3 -c`-Prozesse):**

| Schritt | Aktion | Ergebnis |
|---|---|---|
| 1 | frischer Zustand | 9.8 Hz (94×100ms, 3×200ms) |
| 2 | nochmal derselbe Test, kein UI-Kontakt | 8.4 Hz |
| 3 | nochmal | 6.9 Hz |
| 4 | nochmal | 7.0 Hz |
| 5 | `usb_reset_f9p.sh` (Kernel-Unbind/Bind aller 4 Module, Strom bleibt an) | 7.4 Hz — **kaum Besserung** |
| 6 | Base **physisch aus- und wieder eingesteckt** (echter Stromausfall am Modul) | **10.1 Hz — sauber zurückgesetzt** |

**Zentrale Deduktion:** Jeder Testlauf ist ein komplett unabhängiger, frisch gestarteter `python3 -c`-Prozess — es kann also kein Python-interner State zwischen den Läufen überleben. Die Akkumulation liegt damit nachweislich außerhalb von `gps_measurement.py` und außerhalb von Python generell. Dass selbst das Kernel-seitige USB-Unbind/Bind (Schritt 5 — das Gerät wird aus Sicht des Linux-Treibers vollständig ab- und neu angemeldet) keine Wirkung zeigt, aber das echte Stromtrennen (Schritt 6) sofort resettet, lokalisiert die Ursache **im F9P-Modul selbst** — vermutlich ein interner USB-Peripherie-/Puffer-Zustand in der Empfänger-Firmware, der mit jeder neuen Host-Verbindung (Serial-Open) ohne echten Power-Cycle etwas degradiert.

**Bedeutung für die bisherige Diagnose-Kette:** Widerlegt die Milestone-B-Grundannahme ("Subprocess-Architektur löst Akkumulations-Bug, da sauberer Prozess-Kill") — ein neuer OS-Prozess ändert nichts, weil der Zustand nicht auf OS/Python-Ebene sitzt. NMEA-Multicast-Fix (30.05./14.08.) und RTCM3-Fix (14.08.) waren beide berechtigt und wirksam für den Ruhezustand (sauber 10 Hz vor jeder Nutzung) — lösen aber nicht die Degradation durch wiederholtes Öffnen/Schließen der Verbindung.

**Praktische Konsequenz:** Physisches Kabel-Ziehen zwischen jeder Messung ist im Feld nicht praktikabel. Nächster Test: **UBX-CFG-RST (Hardware-Reset, Hot-Start, `navBbrMask=0`)** per Software an die Base senden — simuliert intern einen Chip-Reset ähnlich dem Stromausfall, ohne Kabel anzufassen. Falls das denselben Reset-Effekt hat wie Schritt 6: Kandidat, um direkt in `start_measurement()` eingebaut zu werden (Reset senden, kurz auf Fix warten, dann erst Messung starten) — würde das Problem für jede Feldsession automatisch lösen.

**Test offen:** UBX-CFG-RST-Test von Falk ausstehend. Falls das NICHT reicht: Fallback wäre eine steuerbare USB-Hub-Stromversorgung (z.B. `uhubctl`, falls der verwendete Hub Port-Power-Switching unterstützt) um den physischen Power-Cycle zu automatisieren.

---

## 2026-08-14 (Fortsetzung) — RTCM3-Multicast-Fix bestätigt + Akkumulations-Bug lebt noch

**RTCM3-Fund (Falk, per u-center direkt an Base):** Auf der Base waren mehrere RTCM3-Messages zusätzlich zu UART2 (Sollzustand laut Architektur: RTCM nur UART2 Base→Rover) noch auf **USB und UART1** aktiv. Rausgenommen. Gleiches Muster wie der NMEA-Multicast-Fund vom 30.05. — nur bei den Korrektur-Messages statt bei NMEA/GGA/RMC/VTG, zusätzliche Output-Operationen pro Zyklus.

**Bestätigt: Fix wirkt.** Isolierter 10s-dt-Test auf Base direkt nach dem RTCM3-Fix, **vor** jedem Start einer Messung über die Web-UI: N=100, dt-Verteilung 97× 100ms + 2× 200ms → **10.0 Hz effektiv, sauber.**

**Neuer, wichtigerer Fund direkt danach:** Web-UI aufgerufen, **eine** Messung gestartet und wieder gestoppt (Service danach wieder gestoppt für den nächsten Isolationstest) — direkt danach derselbe 10s-dt-Test auf Base: N=77, dt = 52× 100ms + 24× 200ms → **7.7 Hz.** Keine Config wurde dazwischen verändert. Einziger Unterschied: `gps_measurement.py` hat einmal den Base-Port geöffnet und wieder geschlossen.

**Einordnung:** Das ist mit hoher Wahrscheinlichkeit der alte **"Akkumulations-Bug"**, dokumentiert am 22.05., 30.05. und 01.06.2026 ("2.-N. Messung (nur Server-Restart): 200-247ms iTOW-Mittel... Nur Pi-Reboot setzt vollständig zurück"). Der wurde damals nie ursächlich gelöst, nur mit `/tmp`-Cleanup + `usb_reset_f9p.sh` pragmatisch für die DLG umschifft, und die systematische Lösung auf Milestone B (Subprocess-Architektur) vertagt. Sieht so aus, als sei er nie weg gewesen — er wurde von der viel dominanteren NMEA/RTCM-Multicast-Drosselung überdeckt, die jetzt gefixt ist.

**Konsequenz für die bisherige Diagnose-Kette:** Die 200ms/5Hz-Werte im Hoftest-CSV vom 05.08. (siehe Eintrag oben) waren vermutlich eine Überlagerung aus zwei unabhängigen Bugs: Base-Multicast (jetzt gefixt) + Start/Stop-Akkumulation (weiterhin offen). Reine F9P-Config-Fixes reichen also nicht für einen im Feld nutzbaren Zustand — nach jedem Start/Stop-Zyklus einer Messung würde man wieder degradieren.

**Test offen (bestätigender Test, von Falk angekündigt):**
1. Pi-Reboot, ohne Website/Messung: Base-Test → erwartet wieder sauber 10 Hz (Baseline-Reset-Verhalten wie in den alten Einträgen beschrieben).
2. Eine Messung starten/stoppen, danach Test → erwartet erneuter Rückgang (Reproduzierbarkeit).
3. Zweites Start/Stop ohne Reboot dazwischen → alte Einträge deuten auf **progressive** Verschlechterung mit jedem weiteren Zyklus hin, nicht nur einen einmaligen Sprung.

**Falls bestätigt:** nächster Fokus verschiebt sich von F9P-Config zurück zu `stop_measurement()`/`start_measurement()` in `gps_measurement.py` — was genau beim Schließen/Wiederöffnen des Serial-Streams einen sauberen Neustart verhindert.

---

## 2026-08-05 — Hoftest UBXReader-Fix: NEGATIV. Root-Cause liegt nicht im Logger.

**Was:** Verifikations-Hoftest für `fix/reader-once-per-thread` (Commit `8b0c6c5`) durchgeführt (Falk, 20:38–20:50 Uhr), 7 Messläufe à 60 s im Hof. CSVs abgelegt unter `data/Records/Reader-once-per-thread/`.

**Ergebnis: Fix hat NICHT gewirkt.** dt-Analyse über alle 7 CSVs (`R1_Rover_time`-iTOW-Diffs):

| Kennzahl | Erwartung | Tatsächlich |
|---|---|---|
| Median dt | ~100 ms | **200 ms** (alle 7 Läufe) |
| Anteil dt ≤100 ms | ≥95 % | 0.1 % |
| Effektive Rate | ≥9.5 Hz | 3.2–5.0 Hz |

RTK-Quality durchgehend 4 (Fix) in allen Läufen — kein GNSS/RTK-Problem.

**Entscheidender Zusatzbefund — Logger-Sync ist NICHT die Ursache:** `R1_Rover_time`, `R2_Rover_time`, `R3_Rover_time` und `Base_Time` sind in **allen 7 Dateien zu 100 % identisch pro Zeile** (0 Mismatches über 1830 Zeilen). Falk hat den Hoftest zusätzlich live per `journalctl -u motionpsm -f` verfolgt — keine einzige "[Logger] dropped X iTOWs"-Meldung. Das heißt: `csv_logger_thread_buffered` (iTOW-Dict, Refactor C) funktioniert exakt wie designed und verliert nichts. Alle vier Threads (Base + R1 + R2 + R3) liefern neue iTOWs bereits **quellseitig nur alle 200 ms im Gleichschritt** — das ist kein Race/Sync-Problem im Python-Code, sondern eine Rate-Begrenzung vor dem Logger.

**Damit sind widerlegt:** Milestone-A-Hypothese (Queue-Konsum vor Toleranz-Prüfung, 17.07.) UND die UBXReader-Neuinstanziierungs-Hypothese (26.07.) als alleinige/hinreichende Ursache — beide sind Logger-/Reader-interne Fixes, aber das Problem sitzt eine Ebene tiefer.

**Neue Hypothese:** Rate-Ceiling auf F9P-Hardware-Ebene, vermutlich analog zum bereits einmal gelösten Fall vom 30.05.2026 ("NMEA-Multicast drosselt intern auf 5 Hz", siehe Eintrag weiter unten) — nur diesmal vermutlich am **Base-Modul**, das laut CLAUDE.md-Stand nie auf `Base_USBonly_v2` geflasht wurde ("Kleinigkeit, 5 Min am Modul" — offener Punkt seit 30.05., nie erledigt). Passt zum Bild: Base_Time läuft im exakten Gleichschritt mit allen 3 Rovern — in Moving-Base-RTK hängt die Rover-RELPOSNED-Rate an den RTCM-Korrekturepochen der Base. Wenn Base intern (NMEA auf allen 5 Ports weiterhin aktiv, nicht USB-only) auf 5 Hz gedrosselt ist, geht das über die RTCM-Kopplung 1:1 auf alle 3 Rover durch — unabhängig vom UBXReader-Fix im Python-Code.

**Sekundärbefund:** in 6 von 7 Läufen zusätzlich 7–21 % der Übergänge bei ~500 ms statt 200 ms (Lauf 1, 20:38 Uhr, war sauber — nur 2×400 ms). Fällt zeitlich mit den geplanten Hand-Auslenkungen an R1/R2 zusammen, vermutlich kurze RTK-Fix-Aussetzer durch Antennen-Anfassen, separates Thema von der 200-ms-Rate-Deckelung.

**Test offen (nächster Schritt, VOR weiterem Code):**
1. CFG-RATE-MEAS auf allen 4 Modulen direkt prüfen (u-center oder `pyubx2 UBX-CFG-VALGET`) — insbesondere ob das am 30.05. verifizierte 100-ms-Setting noch steht, speziell auf der Base.
2. Base-Konfiguration gegen `system/config/f9p_ucenter/usb_only_v2_2026-05-30/` prüfen — Base wurde damals bewusst NICHT geflasht ("war nicht der Bottleneck" laut damaliger NAV-PVT-Messung). Zu klären: ob das unter vollem Moving-Base-RTK-Betrieb im Feld (statt Schreibtisch-Bench-Test ohne RTK-Last) noch stimmt.
3. Falls Base der Flaschenhals ist: `Base_USBonly_v2.txt` flashen (liegt vermutlich schon vor, siehe `f9p_ucenter`-Ordner) und Hoftest wiederholen.

**Risiko:** Kein Blocker für die bereits versendeten DLG-Kurzberichte (Nyquist bei 5 Hz für 0.5–2 Hz Boom-Schwingung weiterhin erfüllt). Blockiert aber weiterhin Milestone B und jede Frequenz-Spektrum-Analyse als Angebot. `fix/reader-once-per-thread` bleibt unangetastet, main bleibt auf `v1.0-dlg` — **kein Merge, kein Tag `v1.1-post-dlg`.**

### Update selber Tag — CFG-Check + Base-USB-only + Einzel-Hz-Test (Falk, ZBook direkt an Modulen)

**CFG-Werte auf Base verifiziert:** `RATE-MEAS=100ms`, `RATE-NAV=1` → angeforderte Rate korrekt 10 Hz (100×1). `RATE-TIMEREF=1 (GPS)` unauffällig. Diese Werte allein beweisen aber nichts über die *tatsächlich erreichte* Rate — dieselbe Lücke gab es schon am 30.05. (Config sagte 10 Hz, Chip lieferte real 5 Hz durch Output-Overload).

**Base MSGOUT auf USB-only umgestellt:** NMEA-GGA/RMC/VTG liefen auf Base noch auf UART/I2C zusätzlich zu USB (Rover waren das seit 30.05. nicht mehr, Base wurde damals bewusst ausgenommen). Auf USB-only gestellt, persistent gespeichert (BBR+Flash, laut Falk bestätigt).

**Isolierter Hz-Test auf Base (Service gestoppt, Antennen dran, Fix erreicht):**
- 5s-Test: 6.2 Hz
- 10s-Test mit dt-Verteilung: **N=67, dt = 33× 100ms + 33× 200ms exakt alternierend, 6.7 Hz effektiv**

**Wichtiger Deutungs-Shift:** Ein reines Rate-Ceiling (Chip berechnet nur alle 200ms eine neue Lösung) könnte niemals 100ms-Abstände produzieren. Dass hier exakt die Hälfte der Übergänge bei 100ms liegt, beweist: **die Base liefert intern tatsächlich 10 Hz**, aber ca. jede zweite NAV-PVT-Message geht zwischen Empfänger und Python-Zählskript verloren — randomisiert, nicht deterministisch. Strukturell dasselbe Symptom wie der UBXReader-Bug vom 26.07., obwohl der Reader in diesem Diagnose-Skript bereits korrekt einmal instanziiert wird (entspricht dem gefixten Pattern). Die Base-USB-only-Änderung hat leicht geholfen (5.0 → 6.2–6.7 Hz), aber nicht das Kernproblem gelöst.

**Neue Arbeitshypothese:** NMEA-Frames (GGA/RMC/VTG laufen weiter auf USB, nur nicht mehr auf UART/I2C) im selben USB-Byte-Stream interleaved mit UBX-Binärframes stören das Parsing/Timing und kosten dabei gelegentlich ein UBX-Frame — eine andere Variante des ursprünglichen "verlorene Bytes im Stream-Puffer"-Mechanismus, diesmal nicht durch Reader-Neuinstanziierung, sondern durch Message-Type-Mischung im Stream.

**Test offen (nächster Schritt):** NMEA auf Base-USB testweise komplett auf 0 (nur RAM/"Send", nicht "Store" — reversibel per Reboot), gleicher 10s-dt-Test wiederholen.
- Wenn dann sauber 100ms ohne Wechsel → NMEA-Interleaving bestätigt als (Teil-)Ursache → dauerhafte Lösung: GGA/VTG auf einen anderen Port (z.B. UART1) verlegen statt USB, damit `gps_measurement.py` (braucht Base_alt/Base_Speed aus GGA/VTG) weiter versorgt wird, ohne den NAV-PVT-Hauptstream zu stören.
- Wenn weiterhin alterniert → kein NMEA-Thema, dann tiefer auf Pi/USB-Treiber-Ebene schauen (`dmesg`, roher Byte-Count wie am 30.05.).

**Noch nicht getestet:** volle 4-Modul-Kette (Rover-Seite) nach der Base-Änderung — der Hoftest mit CSV-Export steht noch aus, ergibt aber erst nach dieser Isolierung Sinn.

---

## 2026-07-28 — Nachtrag: DEVLOG-Lücke Juni/Juli geschlossen

**Was:** Standing Rule #3 (CLAUDE.md) verlangt "wichtige Zwischenstände sofort ins DEVLOG" — das war für den Zeitraum 03.06. bis 26.07.2026 nicht passiert. Die folgenden 5 Einträge (17.07. bis 15.06.) sind rückwirkend rekonstruiert aus Commit-Historie (`git log`) und `data/Feldtage/02_Analyse_Docs/SESSION_LOG_Auswertung.md` (lokal, außerhalb Repo).

**Offener Punkt beim Rekonstruieren entdeckt:** SESSION_LOG_Auswertung.md behauptet für den 17.07. einen Code-Commit `9755749` ("iTOW-Bucket-Dict-Version", Branch `feat/subprocess-refactor`) inkl. Hinweis, der zugehörige DEVLOG-Text sei "lokal geändert (staged)" gewesen, aber wegen eines Sandbox-`index.lock`-Problems nie committed worden — mit der Anweisung, Falk solle das vom Mac aus nachholen. Verifiziert: **Commit `9755749` existiert nicht im Repo** (`git log --all`, `git fsck` — nicht auffindbar, auch nicht unreachable). `origin/feat/subprocess-refactor` steht exakt auf `5a322fe` (DLG-Lock), keinen Commit weiter. Der aktuelle Logger in `system/pi/gps_measurement.py` (`csv_logger_thread_buffered`, Zeile ~544) läuft bereits im iTOW-Dict-Modus — das ist aber Refactor C vom 30.05.2026, nicht die am 17.07. behauptete Änderung. **Der Milestone-A-Commit vom 17.07. ist vermutlich nie über den Sandbox-Lock hinausgekommen und komplett verlorengegangen**, nicht nur der DEVLOG-Text dazu.

**Einordnung:** Praktisch folgenlos — der tatsächliche 5-Hz-Root-Cause war ohnehin ein anderer (UBXReader-Neuinstanziierung, siehe Eintrag 26.07.), der Milestone-A-Fix vom 17.07. war laut SESSION_LOG selbst nur eine Hypothese-basierte Korrektur am alten Queue-Sync-Pattern. Trotzdem: falls in `data/Feldtage/.../PLAN_Phase2-1_2026-07-10.md` (Milestone B / Subprocess-Refactor) auf Details aus dem verlorenen Commit `9755749` aufgebaut werden soll, ist der Code weg und müsste aus dem SESSION_LOG-Text neu geschrieben werden.

**Test offen:** Keiner (reine Dokumentation). Falk ggf. fragen ob `feat/subprocess-refactor` als Branch noch gebraucht wird oder gelöscht werden kann, da er nichts Eigenes mehr enthält.

---

## 2026-07-26 — 5-Hz-Root-Cause gefunden und gefixt: UBXReader pro Thread neu instanziiert

**Branch:** `fix/reader-once-per-thread` (von `main`/`v1.0-dlg`), Commit `8b0c6c5`.

**Was:** In `BaseThread` + `Rover1/2/3_Thread` wurde `UBXReader(stream, validate=0)` bei **jeder** while-Iteration neu erzeugt statt einmal pro Thread. `pyubx2` hält einen internen Byte-Puffer, der beim Neu-Erzeugen verworfen wird — Partial-UBX-Frames aus dem Stream-Puffer gehen dabei verloren. Effekt: jede zweite NAV-PVT/NAV-RELPOSNED-Message wurde verpasst → effektive Rate 5 Hz statt 10 Hz. Fix: Reader wird beim Thread-Start einmal instanziert, danach nur noch `.read()` in der Schleife aufgerufen.

**Warum jetzt erst gefunden:** Der Fix existierte bereits als Experiment `a56b95f` (31.05.2026, Branch `experiment/ubxreader-cleanup`), wurde damals aber nie nach `main` gemerged — genau der Fall, den Standing Rule #2 in CLAUDE.md referenziert ("3 Wochen an einem Bug debuggt der schon längst gefixt war").

**Test offen:** Verifikations-Hoftest am Mittwoch 29.07.2026 abends (Falk), Testplan unter `data/Feldtage/02_Analyse_Docs/TESTPLAN_2026-07-29.md`. Erwartung: Median-dt springt von ~200 ms auf ~100 ms, ≥95 % der Samples ≤100 ms. Bei Erfolg: Merge nach `main`, Tag `v1.1-post-dlg`, danach Milestone B (Subprocess-Architektur) starten.

**Risiko:** Nur `gps_measurement.py` geändert (14+/4−), Reader-Threads sonst unverändert. Kein Risiko für die bereits versendeten DLG-Kurzberichte — deren Std-Abw-Kennzahlen bleiben bei 5 Hz gültig (Nyquist für Boom-Schwingung 0.5–2 Hz erfüllt), nur Frequenz-Spektrum-Analysen (Angebot in den Kurzberichten) brauchen die 10 Hz.

---

## 2026-07-17 — Sample-Rate-Diagnose Phase 2.1: Bug isoliert (Hypothese, siehe Nachtrag oben)

**Was:** Hz-Test am Pi (Falk) zeigt Base + alle 3 Rover feuern einzeln bei 10 Hz — F9P-Konfiguration damit als Ursache ausgeschlossen. Als Kandidat identifiziert: `.get()`-Aufrufe auf den Sync-Queues konsumierten Samples, bevor die iTOW-Toleranz-Prüfung lief — bei Mismatch wurden Samples verworfen statt zurückgelegt, Race zwischen asynchron befüllenden Reader-Threads. Offline-Simulator-Test (Worst-Case-Reordering) zeigte 0/200 vs. 200/200 emittierte Samples zwischen alt/neu.

**Siehe Nachtrag 2026-07-28 oben:** der zugehörige Commit `9755749` ist nicht im Repo auffindbar — dieser Eintrag dokumentiert die Diagnose, nicht einen verifizierten Merge-Stand.

**Test offen (damals geplant, nicht mehr relevant):** Feld-Test im Hof — wurde vermutlich nie durchgeführt, da der Root-Cause sich am 26.07. als ein anderer herausstellte (siehe oben).

---

## 2026-07-10 — Sample-Rate-Diagnose Phase 1: 5 Hz bei allen 6 DLG-Messläufen bestätigt

**Was:** dt-Analyse über alle 6 DLG-CSVs (5 Hersteller, HORSCH mit 2 Läufen): Sample-Rate konstant 5.0 Hz bei **0 %** der Samples auf 10 Hz. Rate ist stabil, kein Drift.

**Ausgeschlossen durch Korrelationsanalyse:** Multipath auf der Spritze (|r| < 0.15 zwischen dt und Speed/Heading-Rate), Akkumulations-Bug (dt in 1./3. Messdrittel identisch), Antennen-Setup.

**Damalige Hypothese:** Base-Modul hat die USB-only-v2-Config nie erhalten (nur auf Rovern geflasht) → Base intern auf 5 Hz gedrosselt → Sync-Logger zieht alles auf 5 Hz. Bestätigt durch Hz-Test am 10.07. (Base UND Rover liefen tatsächlich alle bei 10 Hz einzeln — die Hypothese "Base gedrosselt" war damit widerlegt, der eigentliche Bug lag im Logger/Reader, siehe Einträge 17.07. und 26.07.).

**Auswirkung auf die bereits versendeten Kurzberichte:** Std-Abw-Werte bleiben belastbar (Nyquist erfüllt für 0.5–2 Hz Boom-Schwingung). Frequenz-Spektrum-Analysen (im Angebotsteil aller 5 Kurzberichte enthalten) brauchen für eine bezahlte Folgemessung aber echte 10 Hz.

**Erzeugte Dateien:** `data/Feldtage/02_Analyse_Docs/SampleRate_Diagnose_2026-07-10.docx` + `.xlsx`.

---

## 2026-07-02 — DLG-Auswertung fertiggestellt, 5 Kurzberichte an Hersteller versendet

**Was:** Auswertung der DLG-Feldtage-Messungen (15.–18.06.2026 Bernburg) für 5 Hersteller-Spritzen (AGRIO, HORSCH, AGRIFAC, AMAZONE, KUHN; HORSCH mit 2 Messläufen, Lauf 1 verworfen). Kern-KPI: Std-Abw. R1/R2 in cm + % der Boom-Länge, Toleranz-Verteilung (±0.1/0.3/0.5 %).

**Methodik-Wechsel auf "Option D"** (Falks Entscheidung, angewendet auf alle 5 Berichte einheitlich): Heading-Rate-Schwelle 3°/s → 2°/s, Speed-Cutoff 3 → 5 km/h, Ausreißer-Cap ±3σ, Median-Zentrierung R1+R2 (Zero-Offset raus). Alle vier Änderungen sind ISO-2631-Standardpraxis, kein Zahlen-Schönen. Größter Effekt: KUHN R2 (±0.5 %-Anteil springt 28 % → 94 %) — lag an einem Tare-Zero-Offset, nicht an der eigentlichen Schwingung.

**KUHN-Caveat:** Antennen mussten aus Montage-Gründen bei 30 m statt am echten 36 m-Boom-Ende sitzen — im Kurzbericht als kursiver Hinweis vermerkt, im internen Vergleich als Klassen-Sonderfall markiert.

**Baseline-Backup** vor der Option-D-Umstellung unter `data/Feldtage/_archiv/backup_baseline_2026-07-02/`.

**Versendet:** 15.06. abends alle 5 `MotionPSM_Kurzbericht_<Hersteller>.docx`. Jeweils 1-seitig: Std-R1/R2-KPI-Kacheln, Toleranz-Tabelle, Angebots-Kasten (Frequenz-Spektrum, R&D-Messungen, Asymmetrie, Fahrgeschwindigkeit) für bezahlte Folgemessung. Kein Hersteller-Vergleich in den Berichten (Vertraulichkeit).

**Danach priorisiert (Falks Ansage 02.07.):** stabile 10 Hz Sample-Rate zuerst, vor Auto-Auswertungs-Pipeline — "sonst automatisieren wir im Zweifel schlechte Daten." Daraus resultierten die Diagnose-Einträge 10.07./17.07./26.07. oben.

**Test offen:** Follow-up mit den 5 Herstellern auf Reaktion/Interesse an Folgemessung — Stand 28.07. noch offen.

---

## 2026-06-15 bis 18 — DLG-Feldtage Bernburg: Live-Messungen bei 6 Hersteller-Vorführungen

**Was:** Vor-Ort-Einsatz des MotionPSM-Systems (`v1.0-dlg`-Stand, Tag `v1.0-dlg` auf `5a322fe`) bei den DLG-Feldtagen. Boom-Schwingungsmessungen an Feldspritzen von AGRIO und HORSCH (30 m-Klasse) sowie AGRIFAC, AMAZONE und KUHN (36 m-Klasse) — HORSCH mit 2 Messläufen (Lauf 1 später verworfen, Lauf 2 als Marken-Repräsentant genutzt), macht 6 Messläufe über 5 Hersteller.

**Warum:** Erster Praxiseinsatz nach dem DLG-Lock (Merge `feature/ui-system-restart` → `main`, 02.06.2026). Ziel: belastbare Vergleichsdaten für Kunden-Kurzberichte und Grundlage für Folgemessungs-Angebote.

**Test offen (Stand 15.06.):** keiner mehr offen — Rohdaten wurden erfolgreich erfasst, Roh-Excels unter `data/Feldtage/6× 20260630_*.xlsx` liegen als Basis für die Auswertung ab 30.06. (siehe Eintrag 02.07. oben).

**Risiko:** Rückblickend erkannt (siehe Eintrag 10.07.): alle 6 Messläufe liefen faktisch mit 5 Hz statt der angenommenen 10 Hz. Kein Blocker für Std-Abw.-KPIs (Nyquist erfüllt), aber relevant für zukünftige Frequenz-Spektrum-Angebote.

---

## 2026-06-02 spaet abends — UI-Politur (Branch feature/ui-system-restart)

Iteration auf dem Reboot/Refresh-Branch nach Falks Feedback:

1. **Filter-Default 0.2 → 0.5 s** (Moving-Average 5 Samples statt 2). Setzt sich in `gps_measurement.py` Default UND `config.example.json`. Falks lokales `config.json` muss zusaetzlich aktualisiert werden. Hintergrund: RTK-Rauschen so klein, dass Smoothed/Raw kaum unterscheidbar war — mit 500 ms-Fenster sichtbarere Glaettung.
2. **Header-Text:** "Real Time Monitor" → "MotionPSM" (oben rechts).
3. **Layout-Restructure:** alle 4 Buttons in eine eigene `action-bar`-Zeile UNTER dem Brand-Header. Reboot/Refresh links, Set Zero + Smoothed/Raw rechts (`justify-content: space-between`). Brand-Header bleibt zweizeilig (Logo + Name).
4. **Logo:** `logo_fjw.png` → `logo_brand.svg`. Das offizielle Firmenlogo aus `business/website/assets/` ist jetzt im Repo unter `system/pi/static/logo_brand.svg`. SVG skaliert sauber bei Tablet-Zoom.

Neue CSS-Klassen: `.action-bar`, `.action-bar-group`, `.sys-btn`, `.sys-btn-reboot`, `.sys-btn-refresh`. Hover-States fuer Reboot/Refresh.

---

## 2026-06-02 abends — UI-Buttons "Reboot" + "Refresh" (Branch feature/ui-system-restart)

**Ziel:** Für DLG zwei UI-Buttons im Brand-Header, mit denen Falk vom Tablet aus den Pi neu starten ODER nur den Service+USB-Reset auslösen kann — ohne SSH am Stand.

**Branch:** `feature/ui-system-restart` (von main da3cda1)

**Aenderungen `server.py`:**
1. Neuer Endpoint `POST /system_restart`:
   - Stoppt laufende Messung sauber
   - `subprocess.Popen(['sudo', '-n', '/sbin/reboot'])` (detached)
2. Neuer Endpoint `POST /system_refresh`:
   - Stoppt laufende Messung sauber
   - `subprocess.Popen(['sudo', '-n', '/bin/bash', tools/motionpsm_refresh.sh])` (detached)
3. HTML im Brand-Header: roter Button **Reboot** + oranger Button **Refresh** rechts neben "Real Time Monitor"
4. JS `systemRestart()` und `systemRefresh()` mit `window.confirm()` Dialog + Alert

**Neue Helper-Skripte:**
- `tools/motionpsm_refresh.sh` — laeuft als root via sudo:
  1. `sleep 1.5` (Flask-Response zurueck zum Client)
  2. `systemctl stop motionpsm.service` (toetet server.py)
  3. `tools/usb_reset_f9p.sh` (USB-unbind+bind)
  4. `systemctl start motionpsm.service` (Server kommt zurueck)
  Loggt nach `/tmp/motionpsm_refresh.log`
- `tools/setup_sudoers.sh` — schreibt `/etc/sudoers.d/motionpsm`:
  ```
  $USER ALL=(ALL) NOPASSWD: /sbin/reboot, /bin/bash <repo>/tools/motionpsm_refresh.sh
  ```
  Selbst-Pruefung via `visudo -c` VOR Installation (kein lockout-Risiko).

**Sicherheit:** sudoers erlaubt EXAKT `/sbin/reboot` und den vollen Pfad zu `motionpsm_refresh.sh`. Wenn jemand das Skript modifiziert um beliebigen Code auszufuehren — der User hat eh die Rechte das Skript zu modifizieren, also kein Privilegien-Eskalation.

**Test-Plan (auf Branch, vor merge nach main):**
1. `git pull && git checkout feature/ui-system-restart`
2. `sudo bash tools/setup_sudoers.sh` (einmalig)
3. `sudo -n /sbin/reboot --help` → muss ohne Passwort gehen
4. UI im Browser - beide Buttons sichtbar
5. **Refresh** klicken → ~15 s warten → F5 → UI wieder da, gleiche Pi-Session
6. **Reboot** klicken → ~60 s warten → F5 → UI wieder da, neue Pi-Session

**Bei Erfolg:** merge `feature/ui-system-restart` → `main`, Tag v1.0-dlg force-move.

---

## 2026-06-02 — Frontend-Polling 1000ms → 100ms (validiert, in v1.0-dlg)

**Befund 02.06. abends, 4-Run-Hof-Test mit Desktop deaktiviert:**
- Pi-OS-Desktop deaktiviert (raspi-config Console Autologin) — `ps aux` zeigt keine Xorg/Wayland mehr, RAM 305 MB used von 7.9 GB
- 4 aufeinanderfolgende 30s-Messungen:
  - Reboot 1 → 118 ms iTOW-Mittel (8.5 Hz)
  - Server-Restart → 158 ms (6.3 Hz)
  - Reboot 2 → 150 ms (6.7 Hz)
  - Server-Restart → 138 ms (7.2 Hz)
- **Akkumulations-Bug ist deutlich abgeschwächt!** Run 4 (Restart) ist sogar besser als Run 3 (nach Reboot). Desktop-Deaktivierung war der relevante Hebel.

**Change:** `setInterval(fetchData, 1000)` → `setInterval(fetchData, 100)` in server.py.

**Warum 100ms statt 1000ms:** Über mehrere Tests am 01./02.06. zeigte sich: 100ms-Polling ergibt bessere CSV-Quote als 1000ms (paradox). Hypothese: bei 100ms ist der Polling-Rhythmus exakt synchron zur 10Hz-Sample-Rate — Flask-Calls fallen in Sample-Lücken, blockieren Producer-Threads weniger. Bei 1000ms passieren die Calls zu sporadisch und treffen oft auf Sample-Ankunft.

**Tag v1.0-dlg force-moved** auf neuen HEAD nach diesem Commit. archive/pre-dlg-2026-06-01 bleibt unverändert als Sicherung.

---

## 2026-06-01 abends — DLG-Lock: /tmp-Cleanup + USB-Reset-Skript

**Befund Akkumulations-Bug (klar bestätigt):**
- Direkt nach Pi-Reboot + F9P-Reboot: iTOW-Mittel **140-155 ms** (≈ 6.5-7 Hz)
- 2.-N. Messung (nur Server-Restart): iTOW-Mittel **200-247 ms** (≈ 4-5 Hz)
- Reproduziert mit beiden Base-Configs (Original und USBonly_v2). Modul ist NICHT die Ursache.
- Frontend-Polling-Reduktion (1000ms) brachte _nichts_ — paradoxerweise zeigte 100ms-Polling die beste Quote.
  Heißt: GIL-Polling allein erklärt den Bug nicht.

**Hypothese:** Pi-USB-Subsystem oder Python-State akkumuliert zwischen Server-Restarts. Nur Pi-Reboot setzt vollständig zurück. Saubere Lösung wäre Subprocess-Architektur (gps_measurement als eigener Python-Prozess, getötet beim Stop) — aber zu viel Refactor 13 Tage vor DLG.

**Zwei pragmatische Quick-Hacks für DLG:**

### 1. `/tmp`-Cleanup nach erfolgreichem CSV-Download
`server.py` `/export`-Endpoint: nach `send_file` über `after_this_request`-Hook alle `/tmp/Records_F9P_*.csv` älter als 30s löschen (gerade gesendete Datei sicher ausgenommen). Nur wenn Response-Status 200/206.

**Warum:** Pi's `/tmp` ist tmpfs (RAM). Bei vielen Test-Runs ohne Cleanup wächst es. Reduziert RAM-Druck.

**Sicherheit:** Cleanup läuft erst NACH erfolgreichem Download — kein Datenverlust möglich.

### 2. `tools/usb_reset_f9p.sh` — F9P USB-Reset ohne Pi-Reboot
Bindet die 4 F9P-USB-Devices über `/sys/bus/usb/drivers/usb/{unbind,bind}` ab und wieder an. Setzt USB-Subsystem-State zurück ohne Reboot (~5s Dauer statt ~60s).

**Verwendung:**
```
# Server vorher stoppen:
sudo systemctl stop motionpsm    # falls Autostart
# oder Strg+C im Server-Terminal

sudo bash tools/usb_reset_f9p.sh

# danach Server wieder starten
```

**Test-Plan:** morgen am Pi testen — wenn nach Reset wieder ~140ms-Mittelwert → Workaround validiert für DLG.

### Was NICHT gefixt ist
- Eigentliche Akkumulations-Ursache (Subprocess-Refactor post-DLG)
- 100ms-Quote im Frontend-Live-View (Live-View ist nicht der CSV-Logger; Visualisierung ist OK)

**Risiko-Abwägung:** kein Code-Risiko (nur additive Maßnahmen). Cleanup im Export ist defensiv (after_this_request-Hook fängt Exceptions, dropt sie still). USB-Reset-Skript wird manuell aufgerufen.

---

## 2026-06-01 — Frontend-Polling 200ms → 1000ms (DLG-Lock-Kandidat)

**Befund:** Hof-Test 21:00 mit lean-producer + stop-cleanup + break→continue zeigte trotz allem **200ms-Pattern in CSV mit 42× "3 Rover gleichzeitig" Drop-Pattern**. Im Log-Output: Browser pollt `GET /data` alle 200ms = 5×/s.

Flask läuft im gleichen Python-Prozess wie Producer-Threads. Pro `/data`-Response: ~30-50ms CPU (math, jsonify, _g für 25 Variablen). Python's GIL → Producer-Threads sind während Flask-Response BLOCKIERT → verpassen NAV-RELPOSNED-Verarbeitung → unvollständige iTOW-Slots → CSV jede 200ms statt 100ms.

**Fix:** Frontend `setInterval(fetchData, 200)` → `setInterval(fetchData, 1000)`. 1 UI-Update pro Sekunde statt 5. Tablet zeigt Boom-Schwingung weiterhin flüssig (Schwingung ist 0.5-2 Hz, Update-Rate 1 Hz reicht für visuelle Demo).

**Erwartung:** Producer-Threads bekommen GIL zurück → 100ms-Quote sollte deutlich steigen.

**Wenn DLG-tauglich:** lean-producer → main merge. DLG-Lock.

---

## 2026-06-01 — Logger: break → continue (letzter Code-Test vor DLG-Lock)

**Hypothese:** Aktuell stoppt der Logger beim ersten jungen unvollständigen iTOW. Komplette spätere iTOWs müssen auf nächsten Cycle warten (max 20ms). Bei kontinuierlichem Stream mit gelegentlichen unvollständigen iTOWs könnte das die Output-Rate begrenzen.

**Change:** `break` → `continue`. Logger iteriert nun durch ALLE iTOWs in samples_by_itow:
- Komplette → schreiben + del
- Zu alte (>SAMPLE_MAX_AGE_MS) ohne komplett → drop + del
- Junge unvollständige → continue (im Dict lassen für nächsten Cycle)

**Erwartung:** wenn ein junger iTOW (z.B. 50ms alt) inkomplett ist, aber der nächste iTOW (10ms alt) komplett — wird der jüngere KOMPLETTE jetzt direkt geschrieben. Vorher blockierte der ältere unvollständige.

**Trade-off:** CSV-Zeilen-Reihenfolge nicht mehr strikt aufsteigend nach iTOW (kann aber via Spalte sortiert werden — keine echte Einschränkung).

**Risiko:** sehr gering. Wenn keine Verbesserung → Bottleneck liegt woanders (vermutlich Producer-Thread-Latency / Multi-Port-USB).

**Test offen:** Bench-Test refactor/lean-producer. Wenn deutlich besser → DLG-Version. Wenn nicht → akzeptieren dass 5-7 Hz mit aktuellem Stand der finale ist.

---

## 2026-06-01 — Stop-Cleanup-Fix: Thread + Stream Lifecycle sauber

**Befund:** Falk hat bemerkt — frischer Server-Start liefert deutlich bessere CSV-Daten als nach mehreren Start/Stop-Zyklen. Drop-Log bestätigt:
- `logger fresh after start`: 32 Drop-Lines, fast keine "3 Rover gleichzeitig"
- `logger ubx` (nach vorherigem Run): 128 Drop-Lines, 82× "3 Rover gleichzeitig"

**Ursache:** Im alten `stop_measurement()`:
- `t.join(timeout=2)` aber Producer-Threads sind in `ubr.read()` mit Serial-Timeout 3s blocking → Join gibt nach 2s auf
- Daemon-Threads laufen im Hintergrund weiter
- Beim nächsten `start_measurement()`: neue Threads + alte = mehr Threads → mehr GIL-Druck → mehr Drops
- `samples_by_itow.clear()` passierte nur in start, nicht in stop → Race möglich

**Fix:**
1. Streams ZUERST schließen → Producer-`ubr.read()` kriegt SerialException → Thread durchläuft Catch-Block → kann stop_event prüfen → endet
2. Join-Timeout auf 4s erhöht
3. `samples_by_itow.clear()` + `csv_data_buffer.clear()` in stop_measurement
4. start_measurement: defensiv prüfen ob alte Messung noch läuft + alte Threads noch leben

**Test offen:** Mehrere start/stop-Zyklen am Pi — sollte konsistent gleich gute Daten liefern wie frischer Start.

---

## 2026-06-01 — Lean Producer Threads: schwere Berechnungen raus, GIL entlastet

**Befund 31.05. (Hof-Tests, alle Browser-Tabs zu):**
Drop-Debug-Output zeigt klares Pattern: in 80.5% der Drops fehlen ALLE 3 ROVER gleichzeitig, Base ist da. 9.8% alle 4 fehlen, 7.3% nur Base. Browser-Polling-Hypothese damit ausgeschlossen.

**Diagnose:** Python GIL erlaubt nur 1 Thread Bytecode auf einmal. Die 3 Rover-Threads machen pro NAV-RELPOSNED:
- `np.linalg.lstsq` für angular_velocity (Linear Regression über 20 Punkte)
- Moving-Average mit sin/cos-Schleife über buffer
- init_heading + abs_heading Logik
- height_boom (Base_alt - Rover_alt)

Bei 30 NAV-RELPOSNED/s (3 Rover × 10 Hz) kämpfen die Threads um den GIL → werden gleichzeitig blockiert → Samples gehen verloren.

**Falks Entscheidung (01.06.):** Viele dieser Berechnungen sind Legacy aus der BA-Zeit und nicht mehr DLG-relevant. Behalten werden pro Rover nur: Heading, delta_Heading, Date, Time, Quality, Lon, Lat, accHeading, N, E, D, alt, Speed. Variante A/B + Filter + Tare bleiben im Logger unverändert (nutzen nur N/E/D).

**Änderungen:**

- BaseThread: `geodesic()` + `Point()` + sin/cos-Heading-Mittelwert raus. Base_Heading bleibt 0 (kommt aus Vektor Base→R3 im Logger).
- Rover1/2/3_Thread: `np.linalg.lstsq` (angular_velocity), `mov_avg_heading` mit sin/cos, `init_heading`/`abs_heading`, `current_vibration_*`, `height_boom` aus Base_alt-Diff — alle RAUS.
- Behalten in jedem Rover: `rel_heading` (direkt aus NAV-RELPOSNED), `delta_heading` (einfache Differenz über letzte 2 Werte).
- CSV-Schema unverändert: alle ehemaligen Berechnungs-Spalten bleiben im Header, Werte sind 0 statt berechnet. Rückwärtskompatibel für Excel-Auswertungen.

**Erwartung:** Producer-Threads sind ca. 5-10× weniger CPU-intensiv pro Message. GIL-Last drastisch reduziert. 100ms-Quote sollte deutlich steigen.

**Nachtrag 01.06.:** `height_boom` doch behalten — aus `-Rover_D * 100` (cm, positiv wenn Rover über Base). Eine Zeile pro Rover-Thread, keine Last-Relevanz.

**Test offen:** Hof-Bench-Test auf `refactor/lean-producer`. Drop-Debug-Output zeigt ob "alle 3 Rover gleichzeitig fehlen"-Pattern verschwindet.

**Risiko:** sehr gering. Wenn keine Verbesserung, einfach zurück auf refactor/logger-itow-dict. Geometrie/Mess-Pipeline (Var A/B, Tare) unverändert.

---

## 2026-05-31 — Rollback: SAMPLE_MAX_AGE_MS 500 → 300

**Befund vom Hof-Test 14:00:** Mit MAX=500 lieferte die CSV durchgängig 200ms-Steps (= 5 Hz effektiv), während die Module per pyubx2-Hz-Test sauber 10 Hz produzieren. Vormittag-Stand (MAX=300) hatte 60.8% bei 100ms erreicht — deutlich besser.

**Rollback:** SAMPLE_MAX_AGE_MS zurück auf 300. Architektur (break-Statement) bleibt unverändert. Stand entspricht commit a0fb3f3 (vor dem 500ms-Experiment).

**Test offen:** erneuter Hof-Bench-Test sollte ~60% bei 100ms reproduzieren. Ist das die Baseline, von der wir auf separatem Branch `experiment/ubxreader-cleanup` weiter optimieren.

---

## 2026-05-31 — SAMPLE_MAX_AGE_MS 300 → 500 ms

**Hintergrund:** Bench-Test 31.05. Hof mit Refactor C zeigte saubere iTOW-Sync
(alle 4 Module pro CSV-Zeile identisch ✓), aber 39% der erwarteten Slots
fehlten (100ms-Quote 60.8%, 200ms-Drops 34.3%). Erklärung: die Module
liefern zwar 10 Hz im Bench-Test, aber im Real-World-Setup skipt jedes Modul
sporadisch mal 1 Sample (USB-Latency, F9P-Bursts). Bei 4 Modulen × 90%
Liefer-Quote = 0.9^4 ≈ 65% komplette Slots — passt zu beobachteten 60.8%.

**Fix:** SAMPLE_MAX_AGE_MS von 300 auf 500 ms erhöhen. Logger wartet
länger auf späte Samples. Wenn nur 1 Modul 200ms verspätet liefert, wird
der Slot trotzdem komplett.

**Risiko:** sehr gering. Bei 10Hz Production = max ~5 Samples gleichzeitig
im Dict statt 3, also ~10 KB statt 6 KB. Pi 5 mit 8 GB RAM ignoriert das.
Lock-Contention bleibt minimal (Sort über max ~10 Keys).

**Test offen:** erneuter Hof-Bench-Test nach Base-USBonly-Flash. Erwartung
>90% bei 100 ms.

---

## 2026-05-30 — Logger-Refactor C: iTOW-Dict statt 4 unsync'd Queues

**Befund:** Auch nach dem USB-only-Configs-Fix (54d1dd4) zeigen die CSV-iTOW-Differenzen nur 62.4% bei 100 ms, 25.1% bei 200 ms, der Rest auch grösser. Effektive Rate: 5.29 Hz statt 10 Hz. Die Module liefern jetzt definitiv 10 Hz (per pyubx2-Hz-Test verifiziert), aber der Logger dropt 38% der Samples.

**Ursache (in der alten Architektur):**

- 4 Producer-Threads (Base, Rover1, Rover2, Rover3) schrieben in 8 separate `queue.Queue`-Instanzen mit `queue.clear() + put()` Pattern (jede Queue maximal 1 Sample tief).
- 1 Consumer-Thread (`csv_logger_thread_buffered`) pollte mit `time.sleep(0.02)`, holte aus jeder Queue mit `.get()`, und prüfte iTOW-Sync per Toleranz (100 ms Rover, 500 ms Base).
- Bei Phase-Versatz der Module: Beispiel — Rover 1 schreibt bei iTOW=200, Rover 2 hat noch iTOW=100 weil USB-Latency 5 ms später. Logger zieht: R1=200, R2=100, R3=200, B=200. Spread 100 ms → an Toleranzgrenze, oft `continue`. Sample weg, Lücke im CSV.
- Plus: die Queues haben kein Verständnis von "wer hat geliefert" — sie liefern einfach den letzten Wert. Wenn die Producer leicht unterschiedlich oft `clear()+put()` machen, kann der Consumer „alte" R1-Werte mit „neuen" R3-Werten mischen. Sync-Logik fängt das nur teilweise ab.

**Lösung (Refactor C):**

Zentrale Sample-Sammlung, gruppiert nach iTOW:

```python
samples_lock = threading.Lock()
samples_by_itow = {}  # iTOW (int ms) → {"r1": {...}, "r2": {...}, "r3": {...}, "base": {...}}
SAMPLE_MAX_AGE_MS = 300

def add_sample(itow, source, payload):
    with samples_lock:
        bucket = samples_by_itow.setdefault(int(itow), {})
        bucket[source] = payload
```

**Producer-Threads:**

Jeder Thread ruft beim NAV-RELPOSNED-Empfang (Rover) bzw. NAV-PVT-Empfang (Base) `add_sample(itow, source, {"outline": ..., "relNED": (N,E,D)})` auf. Outline wird aus dem aktuellen Thread-State (akkumulierte NMEA-Daten) gebaut. Die alten `queue.clear()+put()` Pattern sind komplett raus.

**Consumer (csv_logger_thread_buffered v2):**

```python
while not stop_event.is_set():
    time.sleep(0.02)
    with samples_lock:
        itows_sorted = sorted(samples_by_itow.keys())
        newest = itows_sorted[-1] if itows_sorted else 0
        complete_samples = []
        for itow in itows_sorted:
            sample = samples_by_itow[itow]
            if len(sample) == 4 and all(k in sample for k in ("r1","r2","r3","base")):
                complete_samples.append((itow, sample))
                del samples_by_itow[itow]
            elif newest - itow > SAMPLE_MAX_AGE_MS:
                del samples_by_itow[itow]  # zu alt, drop
            else:
                break  # noch jung, warten
    # CSV-Schreiben außerhalb des Locks (vermeidet Lock-Contention bei langen Operationen)
    for itow, sample in complete_samples:
        ... build CSV line from sample[r1/r2/r3/base].outline + relNED ...
```

**Erwarteter Effekt:**

- 100ms-Lücken-Quote sollte > 95% steigen (von 62.4%)
- 200ms-Drops verschwinden weil keine Race-Condition mehr möglich ist (Samples werden NACH iTOW gruppiert, nicht nach Queue-Eintrag-Reihenfolge)
- Spikes > 500 ms bleiben evtl. drin — die kommen vermutlich von echten USB-Stalls oder Pi-Scheduler-Hängern, das löst dieser Refactor nicht

**Architektur-Vorteile zusätzlich:**

- Lock nur kurz beim Pull aus Dict, CSV-Bau außerhalb → kein Lock-Contention mit Producern
- Memory-bounded durch SAMPLE_MAX_AGE_MS Cleanup (Dict wächst nicht unbegrenzt)
- Easy Debug: `samples_by_itow` ist inspizierbar, vs alte Queues waren opak

**Files geändert:**

- `system/pi/gps_measurement.py`:
  - Globale Queue-Decls (B_Time, B_Message, R_X_Time/Message) → samples_by_itow + samples_lock
  - `add_sample()` Helper hinzugefügt
  - BaseThread, Rover1/2/3_Thread: queue.clear+put → add_sample bei NAV-PVT/RELPOSNED
  - csv_logger_thread_buffered komplett neu (Dict-Konsumption)
  - start_measurement(): Queue-Globals aus globals raus, samples_by_itow.clear() bei Start

**Test offen:**

- Bench-Test am Pi: `git checkout refactor/logger-itow-dict`, `git pull`, Server starten, 30s messen, CSV-iTOW-Verteilung analysieren. Erwartung: > 95% bei 100 ms.
- Falls bestätigt → merge nach main
- Wenn problematisch (z.B. Memory-Leak oder Lock-Contention): zurück auf main, weiter analysieren

**Risiko:**

- Mittel. Architektur-Umbau betrifft kritischen Datenpfad. Aber: durch Branch isoliert, jederzeit zurückrollbar mit `git checkout main`.
- Edge Case: wenn ein Modul länger als 300 ms ausfällt, droppen wir frühe Samples. Bei DLG-Anwendungsfall (RTK-Fix-Verlust) ist das aber gewünscht — kein Müll-Sample mit Mixed-Time-Daten.

---

## 2026-05-30 — 5-Hz-Problem auf USB gelöst: NMEA-Multicast war die Ursache

**Befund:** Trotz CFG-RATE-MEAS = 100 ms (= 10 Hz) auf allen Modulen lieferte der CSV-Logger nur 5 Hz effektive Sample-Rate (Lücken bei 200 ms statt 100 ms). Der Sleep-Fix vom 22.05. (time.sleep 0.1 -> 0.02) hatte keinen Effekt — er war notwendig aber nicht ausreichend.

**Diagnose:**

Per `cat /dev/serial/by-id/usb-R_N-if00 | wc -c` über 5 Sekunden gemessen, mit Antennen + RTK:
- Base: ca. 82 KB / 5s
- Rover 1/2/3: je ca. 44 KB / 5s (= halb so viel wie Base)

Genau-Hz-Test mit pyubx2 zeigte: alle Rover bei NAV-RELPOSNED nur 5 Hz, Base bei NAV-PVT 10 Hz. CFG-RATE war aber bei allen Modulen korrekt auf 100 ms gesetzt — verifiziert in u-center.

Tiefe Konfig-Analyse via UBX_CONFIG_DATABASE (pyubx2): die u-blox Configs hatten **NMEA-GGA, NMEA-RMC, NMEA-VTG auf ALLEN 5 Ports aktiviert** (I2C + UART1 + UART2 + USB + SPI). Plus NAV-RELPOSNED auf 3 Ports (UART2 + USB + SPI). Das sind 18 Output-Operationen pro Mess-Zyklus pro Rover. Bei 10 Hz Mess-Rate intern hat der ZED-F9P sich **auf 5 Hz NAV-RELPOSNED-Output gedrosselt**, weil er die 180 Output-Operationen pro Sekunde plus die normale Mess-Verarbeitung nicht parallel schaffte.

Die Base war NICHT betroffen: sie sendet NAV-PVT statt NAV-RELPOSNED (kleinere Message) und hat ihren UART2-RTCM-Output (Moving-Base-Korrektur zu Rovern) der nicht mit NMEA-Multicast konkurriert.

**Fehlversuch v1 (Configs `usb_only_2026-05-25/`, NICHT im Repo gelandet):**

Erstes Skript hatte geschätzte Item-IDs für die CFG-MSGOUT-Keys verwendet. Annahme war: I2C, UART1, UART2, USB, SPI laufen sequentiell bei 0xXX, 0xXX+1, +2, +3, +4. Für die meisten Messages stimmt das (NMEA-GGA: I2C=BA, UART1=BB, UART2=BC, USB=BD, SPI=BE) — aber **NAV-RELPOSNED beginnt bei 0x8D statt 0x8C**:
- NAV-RELPOSNED I2C = 0x8D, UART1 = 0x8E, UART2 = **0x8F**, USB = **0x90**, SPI = 0x91

Mein Off-by-one-Skript identifizierte 0x8F als USB (= war UART2) und 0x90 als SPI (= war USB). Effekt nach Flash auf Rover 1/2/3: USB-Output abgeschaltet, UART2-Output aktiv geblieben — Pi konnte kein NAV-RELPOSNED mehr lesen. Falk hat das in u-center selbst entdeckt ("USB = 0, UART2 = 1, ist das richtig?").

**Lösung v2 (`usb_only_v2_2026-05-30/`, dieser Commit):**

Neues Skript nutzt direkt `pyubx2.UBX_CONFIG_DATABASE` als autoritative u-blox-Doku-Quelle (1268 Config-Keys). Pro Key kann der Port aus dem Namen extrahiert werden, Item-IDs sind exakt. Pro Original-Config: nur USB-Variants behalten = 1, alle anderen UBX/NMEA-Ports auf 0. RTCM-Keys (high byte != 0) bleiben unangetastet — kritisch fuer Base-UART2-RTCM-Output.

Vier Configs erzeugt:
- `Falk_weigand_config_Base_USBonly_v2.txt`
- `Falk_weigand_config_Rover1_USBonly_v2.txt`
- `Falk_weigand_config_Rover2_USBonly_v2.txt`
- `Falk_weigand_config_Rover3_USBonly_v2.txt`

Falk hat R1/R2/R3 in u-center geflasht + persistent in BBR/Flash gespeichert (Base blieb auf Original-Stand — sie war nicht der Bottleneck).

**Verifikation:**

pyubx2-Hz-Test direkt auf Pi (alle Module ohne Antennen, am Schreibtisch):
- Base: NAV-PVT 10.0 Hz, NMEA-GGA/RMC/VTG je 10.0 Hz
- Rover 1: NAV-RELPOSNED **10.0 Hz**, NMEA je 10.0 Hz
- Rover 2: NAV-RELPOSNED **10.0 Hz**, NMEA je 10.0 Hz
- Rover 3: NAV-RELPOSNED **10.0 Hz**, NMEA je 10.0 Hz

Anschliessend Hof-Test mit Antennen + RTK + Tare-Sequenz (CSV `Records_F9P_20260530_131028.csv`):
- 10 cm physisch ausgelenkt -> -10 cm gemessen in `VarA_R2_longitudinal_tared_cm` (Zeilen 150-175)
- 20 cm physisch ausgelenkt -> -20 cm gemessen (Zeilen 180-200)
- Zuruck auf Stand -> 0 cm +/- 1.5 cm Rauschen

Geometrie + Tare-Logik damit zum 2. Mal validiert (nach 22.05. mit 10 cm). Mess-Konzept ist solid fuer DLG.

**Test offen:**

CSV-Auswertung der iTOW-Differenzen zeigt: **62.4% der Zeilen-Uebergaenge bei 100 ms** (= Soll), aber 25.1% bei 200 ms, 7.5% bei 300-500 ms, 5% Spikes bis 2600 ms. Effektive mittlere Rate: 5.29 Hz. **Die Module liefern jetzt sauber 10 Hz, aber der CSV-Logger droppt 38% der Samples** wegen Race-Conditions in der 3-Wege-Sync-Logik. Das ist die alte Logger-Architektur mit 4 separaten `queue.clear() + put()` pro Producer — bei Phase-Versatz der Module misst die Sync-Toleranz fail.

Naechster Schritt (separater Branch `refactor/logger-itow-dict`): Logger umbauen auf zentralen iTOW-keyed dict statt 4 unsync'd Queues. Erwartung: > 95% bei 100 ms.

**Risiko des aktuellen Stands:**

Fuer DLG-Boom-Schwingungsmessung (0.5-2 Hz Frequenzinhalt) ist 5 Hz Nyquist-konform, also funktional ausreichend. Aber 38% Sample-Drops sehen in einer Live-Demo unprofessionell aus, und die Spikes bis 2.6 s reissen wirklich Loecher in die Auswertung. Refactor sollte vor 15.06. fertig sein.

**Konfig-Hinweis fuer zukuenftige UBX-Modifikationen:**

NIEMALS Item-IDs schaetzen oder aus Beobachtungen abloeschen. Immer `from pyubx2 import UBX_CONFIG_DATABASE` und das Reverse-Lookup nutzen. 1268 Keys decken praktisch alle ZED-F9P-Settings ab und stammen direkt aus der u-blox Interface Description.

---

## 2026-05-22 — Logger-Sleep-Fix: 10 Hz statt 5 Hz effektive Sample-Rate

**Beobachtung aus Testfahrt 22.05.2026 (Spritze, Base+R3 am Spritzen-Chassis, R1/R2 an Gestängeenden):**

Stillstands-Messung sauber (10 cm Auslenkung gemessen = 10 cm angezeigt — Geometrie + Tare + Variante A validiert).

Aber während der Fahrt zeigte das CSV **iTOW-Abstände von dauerhaft ca. 200 ms** (= effektiv 5 Hz statt eingestellter 10 Hz), plus 2-3 Spitzen bei ca. 1800 ms.

**Ursache:**

In `system/pi/gps_measurement.py` Zeile 724 (im `csv_logger_thread_buffered`):

```python
while not stop_event.is_set():
    time.sleep(0.1)        # 100 ms Pause vor jedem Sync-Check
    ...
    # 4 queue.get(), Sync-Check, 81-Spalten _fmt(), Disk-Write (~50 ms)
```

Logger-Zyklus = 100 ms Sleep + ~50 ms Verarbeitung ≈ **150 – 200 ms** → effektiv 5 – 7 Hz, egal wie schnell die Module liefern.

**Verifiziert:** Die u-blox-Configs (`f9p_ucenter/Falk_weigand_config_Base/Rover1/2/3.txt`) sind alle korrekt auf 100 ms = 10 Hz konfiguriert. NICHT die Ursache war:
- RTK-Qualität (immer Fix=4 auf allen Rovern während Test)
- NumSV (stabil 12 für Base)
- Module-Konfiguration (alle 4 Configs zeigen 10 Hz)
- Pi-Thermal (jetzt mit offener Box bei 54 °C, kein Throttling)

**Fix:**

```python
time.sleep(0.1) -> time.sleep(0.02)  # 50 Hz Logger-Poll-Zyklus
```

Logger wacht jetzt 5x pro 100-ms-Sample-Periode auf. Sync-Checks gelingen sofort, Queues bleiben praktisch leer. CPU-Last marginal höher (Pi 5 mit 8 GB lacht darüber).

**Bewusst NICHT geändert:**

Die Sync-Logik selbst (4 separate Queues, `if empty(): continue` Pattern) hat einen latent vorhandenen Architektur-Bug: bei Race-Conditions (z.B. wenn ein Modul kurz lag und die Queues unbalanced füllt) können Samples falsch zugeordnet werden. Strukturell sauberer wäre ein **iTOW-Dictionary** als zentraler Sammelpunkt. **Aber das ist ein 50-Zeilen-Refactor und kommt POST-DLG** (Ansatz C in der Architektur-Diskussion vom 22.05.).

Ein zwischenzeitlich angedachter Fix mit `get_nowait()` wurde verworfen, weil er ein Daten-Verlust-Risiko mitbrächte: wenn ein Modul gerade nichts in der Queue hat, würde der erste erfolgreiche `get_nowait()` das Sample der vorherigen Module konsumieren, dann werfen — Samples wären verloren. Die original `if .empty(): continue`-Variante schützt davor.

**Test offen:**

- Bench-Test am Pi: Logger 60 s laufen lassen, neue CSV inspizieren. Erwartung: iTOW-Lücken durchgehend bei 100 ms +/- 20 ms (also tatsächliche 10 Hz).
- Testfahrt nach Active-Cooler-Einbau + neue Box (siehe TODO.md Hardware): Verifikation unter realistischer Last + Vibration.
- Die 1800-ms-Spitzen sind vermutlich USB-/Vibrations-bedingte Module-Stalls — werden vom Sleep-Fix moeglicherweise nicht vollstaendig adressiert. Beobachten und ggf. mit Architektur-Refactor (Ansatz C) post-DLG fixen.

**Risiko:**

Sehr gering. Eine Zeichen-Änderung, leicht rückgängig zu machen. Falls aus unerklärlichen Gründen unter sehr hoher Last (z.B. SD-Karte fast voll, anderer Prozess belegt CPU) der Logger doch CPU-bound wird, könnte die System-Reaktion träger werden — aber Pi 5 hat dafür mehr als genug Reserven.

---

## 2026-05-17 — Hardware-Erkenntnis: Base muss am Schlepper, nicht am Gestänge

**Beobachtung aus Test-Fahrt Records_F9P_20260516_171707_ausg.xls:**

Bei einer 73°-Kurvenfahrt (sichtbar im `Axis_R3_heading_deg`-Plot: 145° → 72°) blieb das Gestänge mit ~17 cm Symmetric Yaw verdreht hängen (R1 ≈ −15 cm, R2 ≈ +20 cm im Endstand). Zusätzlich schwankte `Axis_R3_length_m` während der Fahrt um 4 cm (4.97 ↔ 5.03 m) — sollte konstant sein bei festem R3.

**Ursache:** Base war auf der gezogenen Spritze selbst am Gestänge montiert. Damit:
- Base schwingt mit dem Gestänge mit
- `relPosNED` ist Rover-Position minus Base-Position → Schwingung der Base wird von der Rover-Schwingung abgezogen
- Reale Gestängebewegung wird systematisch zu klein gemessen
- Achse Base→R3 wackelt, weil Base als Bezugspunkt selbst nicht ruhig ist
- Base hat zudem schlechtere Sky-View am Gestänge → schlechtere RTK-Qualität

**Hardware-Regel ab jetzt:**
- **Base am Schlepperdach** (oder höchster fester Punkt am Schlepper), maximale Sky-View
- **R3 ebenfalls am Schlepper** (Anbaubock, vorne in Fahrtrichtung) — definiert Längsachse aus zwei schlepperfesten Punkten
- **R1, R2 am Gestänge-Ende** — die einzigen Punkte die wirklich schwingen sollen
- Damit ist die Achse Base→R3 garantiert stabil und `relPosNED` für R1/R2 misst echte Gestängebewegung 1:1

**Halterung-Tipp (Falks Eigenkonstruktion):** Antennen mit Rohrklemmen aus Kamerazubehör auf Standardrohren befestigt. Funktioniert sehr gut, vibrationsfest. Wird übernommen für alle Aufbauten.

**Folge für Daten-Validität:**
Die Test-Daten vom 16.05. (Base am Gestänge) sind als Konzept-Validierung brauchbar, aber für quantitative Aussagen nicht final — die 17 cm Restverdrehung könnte teilweise Base-Schwingungs-Artefakt sein, teilweise echte mechanische Hysterese im Gestänge. Mit Base am Schlepper (ab Dienstag 19.05.) werden die Werte sauberer.

**Test offen:**
- Dienstag 19.05.: Neuer Aufbau mit Base + R3 am Schlepper, R1/R2 am Gestänge. Vorher Tare drücken.
- Erwartung: `Axis_R3_length` stabil ±1 cm, R1/R2 longitudinal im Stand sauber bei 0, nach Schwingungsabklingen wieder ≈ 0 (außer echte mechanische Verdrehung).

---

## 2026-05-17 — Mathematik-Beweis: Variante A ist rotationsinvariant

**Frage Falks:** Wenn die Maschine Kurven fährt, verschiebt sich dann mein gemessener longitudinal-Wert durch das wechselnde Maschinen-Heading?

**Antwort:** Nein. `VarA_R1_longitudinal_cm` ist mathematisch invariant gegen Maschinen-Rotation, sofern R3 wirklich fest am Schlepper sitzt.

**Beweis (kurz):**
Sei R_θ die Rotationsmatrix der Maschine um Winkel θ. Bei reiner Rotation gilt:
```
R1_NED' = R_θ × R1_NED
R3_NED' = R_θ × R3_NED
Achsen_Einheitsvektor' = R_θ × Achsen_Einheitsvektor
longitudinal' = R1_NED' · Achsen_Einheitsvektor' = R1_NED · Achsen_Einheitsvektor = longitudinal
```
(Skalarprodukt ist rotationsinvariant.)

**Praktische Implikation:** Wenn nach einer Fahrt die R1/R2 longitudinal-Werte nicht in 0 zurückkommen, ist die Ursache:
1. Reale mechanische Verdrehung des Gestänges (Hysterese, gehemmter Pendel-Rückgang)
2. R3 hat sich physisch relativ zum Schlepper verstellt
3. Slow Phase-Drift (Ionosphäre, Antennen-PCO) — typisch nur wenige cm

**NICHT die Ursache:** das Maschinen-Heading. Die alte Sorge vor "Heading-Drift" ist mit R3 mathematisch abgedeckt.

---

## 2026-05-17 — Tare-Funktion (Set Zero / Clear)

**Was:** UI-Button "⌖ Set Zero" oben rechts (links neben Smoothed/Raw-Toggle, dezent gestaltet) speichert die aktuellen longitudinal+lateral-Werte von R1 und R2 als Nullpunkt-Referenz. Alle nachfolgenden Live-Werte und CSV-Spalten `VarA_R*_*_tared_cm` werden gegen diesen Offset berechnet. Status "Tared HH:MM:SS" zeigt aktiven Tare-Zustand mit `×`-Button zum Clear.

**Warum:**
- Rover sind nie 100% perfekt symmetrisch zur Längsachse montiert (z.B. R1 sitzt 5 cm weiter vorne als R2) → ohne Tare permanente Offsets
- Nach RTK-Re-Fix oder Halterung-Verstellung kann man auf aktuelle Position nullen ohne Code-Eingriff
- Workflow: Maschine fertig aufgebaut + still → Set Zero → Messung starten → alles relativ zur Ausgangslage

**Implementation:**
- `gps_measurement.py`: Module-Globals `TARE_R1/R2_LONG/LAT_CM` + `TARE_SET_AT`, plus `set_tare()` / `clear_tare()` Funktionen
- `server.py`: Endpoints `/zero` (POST/GET) und `/zero/clear` (POST/GET); `/data` subtrahiert Offsets vor Auslieferung
- CSV bekommt 5 zusätzliche Spalten am Ende: `VarA_R1/R2_longitudinal/lateral_tared_cm` + `Tare_set_at`
- Roh-Werte bleiben im CSV erhalten — Post-Processing-Flexibilität

**Bewusst NICHT persistent:** Tare-Werte werden nicht in eine JSON gespeichert, sondern bleiben nur pro Pi-Session. Begründung: modular auf verschiedene Spritzen — jede Spritze braucht eigenes Tare beim Aufbau.

**Test offen:** Dienstag 19.05. erste Praxis-Nutzung im Maschinen-Setup.

---

## 2026-05-17 — Filter-Iteration: Moving-Average + UI-Toggle Smoothed/Raw

**Was:**
- `config.json` neues Feld `FILTER_WINDOW_S` (Default 0.2 s = 2 Samples bei 10 Hz Sample-Rate). Höhere Werte = mehr Glättung + mehr Verzögerung.
- `gps_measurement.py`: Moving-Average-Buffer in `start_measurement()` initialisiert, im Logger berechnet. Module-Globals `R1/R2_longitudinal_filtered_cm`.
- `server.py` `/data` Endpoint: 4 neue Felder (`r1/r2_longitudinal_filtered_cm`, `symmetric/asymmetric_yaw_filtered_cm`).
- UI: Toggle "Smoothed | Raw" oben rechts. Default = Smoothed. Persistent in localStorage (Key `motionpsm_data_mode`).
- CSV bekommt **immer** beide Spaltensätze (raw + filtered), unabhängig vom UI-Toggle — für Post-Processing-Flexibilität: 6 neue Spalten (`VarA_R*_longitudinal_filtered_cm`, `Symmetric/Asymmetric_Yaw_raw/filtered_cm`).

**Warum:**
- Im Stand schwanken die Rover-Werte auch bei RTK Fix um wenige cm (Multipath, Phase-Drift). Beim Lesen der Live-Anzeige war das verwirrend.
- Echte Boom-Schwingungen sind typisch 0.5–2 Hz (Periode 0.5–2 s) — diese kommen durch einen 0.2-s-Filter quasi unverändert durch.
- Der `FILTER_WINDOW_S`-Wert ist im Feld änderbar ohne Code-Eingriff.

---

## 2026-05-17 — Bug-Fix: relPosN/E/D Skalierung (Faktor 100 zu groß)

**Symptom:** `Detected Boom Width` im Frontend zeigte 40 m statt 4 m. Im CSV waren `VarA_R*_lateral_cm` 100× zu groß (z.B. 47500 statt 475).

**Ursache:** u-blox `NAV-RELPOSNED` liefert via pyubx2 die `relPosN/E/D`-Werte als **raw cm-Integers**, nicht als Meter. Der alte Code behandelte sie als Meter, dann wurden sie im Logger nochmal × 100 für cm umgerechnet → Faktor 100 zu groß.

**Fix:** in den drei Rover-Threads:
```python
Rover_N = ((parsed_data.relPosN or 0) + (getattr(parsed_data, 'relPosHPN', 0) * 1e-2)) * 1e-2
```
Erklärung: `(relPosN_cm + HPN × 0.01_cm)` ist die volle Position in cm; `× 0.01` konvertiert in Meter. Analog Rover_E, Rover_D.

**Verifiziert mit Falks CSV Records_F9P_20260515_123745.csv:**
- Rover_1_N war 475.58 cm fehlinterpretiert, jetzt 4.7558 m ✓
- Rover_2_N war −464.38 cm, jetzt −4.6416 m ✓
- Rover_3_E war 513.04 cm, jetzt 5.1304 m ✓

---

## 2026-05-17 — UI-Iteration: longitudinal als Hauptmetrik, Logo, Roboto, Englisch

**Erkenntnis von Falks erstem Frontend-Test:** Das ursprüngliche Layout zeigte `lateral_offset_cm` als Hauptmetrik. Aber lateral ist im Ruhezustand ≈ halbe Gestängebreite (≈ konstant), nicht die Schwingung. **Die echte Schwingungs-Metrik ist `longitudinal_cm`** (Vor-/Rückwärts-Komponente entlang der Fahrtrichtung).

**Umgebaut:**
- Hauptanzeige im Hero: `R1/R2 longitudinal` + `Symmetric Yaw` + `Asymmetric Yaw` + Winkel R*-Baseline
- SVG-Layout neu: Top-Down View. R1/R2-Marker wandern vertikal mit longitudinal-Wert. Soll-Position als grauer Schatten.
- Skalierung automatisch dynamisch aus den gemessenen Werten, keine manuelle Boom-Width-Eingabe mehr nötig.
- Branding: FJW-Logo (Logo_FJW_Final.png) oben links + Schriftzug "FJW Systems / MOTIONPSM". "Real Time Monitor" oben rechts in gleicher Größe.
- Komplett englisch.
- Roboto als Schriftart (passt zur Briefvorlage).
- Heading-Schwingung-Plot raus (nur Deflection-History bleibt).
- R3-Marker im SVG: transparent (45 %) und näher am Gestänge.

**GeoGebra-Referenz für Konvention:**
- Symmetric Yaw = (R2_long − R1_long) / 2 → entspricht Falks Symmetrisches-Gieren-Sketch (R1 negativ, R2 positiv bei positivem α)
- Asymmetric Yaw = (R1_long + R2_long) / 2 → reine Translation des gesamten Gestänges
- Vorzeichen: + = nach vorne in Fahrtrichtung

---

## 2026-05-17 — Autostart + Pi-Setup-Pipeline

**Was:** Drei neue Files in `system/pi/`:
- `setup_pi.sh`: Einmaliger Pi-Setup. apt-Pakete (python3-venv, git, pip), venv unter `<repo>/.venv/`, pip install -r requirements.txt, config.json aus Template.
- `requirements.txt`: flask, pyserial, pyubx2, pyproj, numpy, geopy
- `autostart_schwingung_fw.sh` + `motionpsm.service.template` + `install_autostart.sh`: systemd-Service mit Pfad-Auto-Detection, USB-Wait (10 s), Restart-on-failure, journalctl-Logging.

`documentation/PI_SETUP.md`: Schritt-für-Schritt-Anleitung von frischem Pi-OS bis "Service läuft beim Boot", inkl. Trouble-Shooting-Tabelle und Update-Workflow.

**Warum:** Alter Autostart hatte hardcoded BA-Pfade (`/home/ba_weigand/software/final/...`) und war nicht systemd-basiert. Neue Lösung ist portabel (Repo kann überall liegen), user-agnostisch (Installer erkennt User), und resistent (Restart-on-failure).

**Status (17.05.):** Falk nutzt vorerst manuellen Start ohne Autostart. Autostart wird aktiviert, sobald das System ein Wochenende ohne Eingriff durchgelaufen ist.

---

## 2026-05-11 — Visualisierung neu: Gestänge-Hero + alle 3 Rover + Längsachse

**Was:**

`system/pi/server.py` komplett neu strukturiert. UI-Fokus von Heading-Charts auf **Gestänge-Auslenkung in cm** verschoben.

Layout (von oben nach unten):
1. **Hero "Aktuelle Gestänge-Auslenkung"**:
   - Eingabefeld Gestängebreite (cm), Default 1500
   - Schematisches SVG: horizontale Linie mit R1-Marker (links, blau), R2-Marker (rechts, rot), R3-Marker oben (grün, "Fahrtrichtung"), Mittelachse als gestrichelte Linie. Die Marker bewegen sich live mit `lateral_offset_cm`.
   - Drei Wert-Boxen: R1-Auslenkung (cm, signed), Gesamt-Differenz R1−R2 (cm), R2-Auslenkung (cm, signed)
2. **Quality-Grid + Achse-Info nebeneinander**:
   - Quality-Tabelle pro Rover (Fix-Type-Badge, Angular Velocity, Schwingung in °)
   - Längsachse Base→R3: Länge in m, Heading in °, plus Fahrgeschwindigkeit
3. **Zwei Live-Charts (kleiner)**:
   - Verlauf lateral_offset R1/R2/Differenz (cm)
   - Heading-Schwingung R1/R2/R3 (° mov_avg)

`/data` Endpoint erweitert auf 16 Felder (neue: r1/r2_lateral_cm, gestaenge_total_cm, axis_length_m, axis_heading_deg, r3_quality, r3_angular_velocity, r3_vibration). Alle returnen JSON-safe (`round` für Floats, Fallback 0 für None).

CSS responsive (Grid bricht auf 1-Spalte um bei <800px). Polling-Intervall 200 ms.

**Warum:**

- Alte UI zeigte nur ° (Heading) — für den User schwer interpretierbar im Feld. Cm-Auslenkung der Boom-Ausleger ist direkt und intuitiv.
- Gestängebreite-Input ist Live-konfigurierbar (vom User vor Ort einstellbar), wirkt nur auf die SVG-Skalierung — Daten selbst bleiben unverändert.
- Rover 3 ist jetzt erstklassig sichtbar (Quality-Reihe + Achsen-Info). Längsachse Base→R3 wird live als Länge + Heading angezeigt — direkter Sanity-Check: Länge sollte stabil sein (≈ physische Distanz Base zu R3, z.B. 2-3 m), Heading sollte mit Fahrtrichtung übereinstimmen.

**Test offen:**

- Frontend in Chrome / Safari / Firefox am Tablet/Smartphone testen (responsive Layout).
- SVG-Marker-Bewegung bei extremen Werten (>> Gestängebreite/2): Marker rutschen außerhalb der SVG-Box. Aktuell wird ohne Clipping gerendert — bewusst, damit Anomalien sichtbar bleiben.
- Performance bei längerer Messung: Charts haben CHART_MAX_POINTS = 80 Sliding-Window — sollte fluffig bleiben.

**Risiko:**

- Bei R3-Ausfall (RTK lost) sind `lateral_offset_cm` Werte = 0 (Fallback in gps_measurement.py). Die UI würde dann "R1=0, R2=0" anzeigen — verwechselbar mit "Gestänge gerade". Mitigation: Quality-Badge zeigt rot/grau bei R3 → User erkennt sofort, dass Daten nicht trauenswürdig.
- `boom_total = lateral_r1 − lateral_r2` ist als rohe Differenz definiert. Bei symmetrischer Aufhängung sollte das im Stand ≈ 0 sein. Falls Falks Setup asymmetrisch ist (z.B. R1 weiter draußen als R2), ist `boom_total` permanent verschoben — nicht falsch, aber interpretationsbedürftig.

**Vor erstem Lauf am Pi:**

Pi braucht Flask + die anderen Python-Deps. Sollte schon installiert sein vom alten Stand. Falls nicht:
```bash
pip install flask pyserial pyubx2 pyproj numpy geopy
```

---

## 2026-05-11 — PROJECT_CONTEXT.md angelegt

**Was:** `documentation/PROJECT_CONTEXT.md` mit Cold-Start-Briefing für neue Cowork-Sessions: Wer/Was, Hardware, Mess-Konzept, Repo-Struktur, Termine, Konventionen, Tech-Stack.

**Warum:** Cowork hat keine "Projects"-Feature wie claude.ai. Mit einem zentralen Kontext-File startet jede neue Session sofort produktiv — Falk muss nur "lies PROJECT_CONTEXT.md" sagen.

---

## 2026-05-11 — Rover3-Erweiterung: Längsachse + Mittelachsen-Projektion

**Was:**

Neuer Branch `feature/rover3`. Rover 3 sitzt vorne in Fahrtrichtung am Schlepper. Der Vektor Base→R3 definiert die geometrische Längsachse der Maschine — sauberer und im Stillstand stabiler als das bisherige Verfahren (Base-Heading aus Eigenbewegung).

Neue Files:
- `system/pi/geometry.py` — Helper-Modul mit:
  - `vehicle_axis(relNED_r3)` → Achsenlänge, Einheitsvektor (aN_hat, aE_hat), Heading
  - `lateral_offset_a(relNED_rover, aN_hat, aE_hat)` → Variante A: Querauslenkung
  - `diff_vector_b(relNED_target, relNED_reference)` → Variante B: Differenzvektor
  - Konvention: lateral_m > 0 → Rover links der Mittelachse (Fahrer-Perspektive)
  - MIN_AXIS_LENGTH_M = 0.05 (5 cm Mindestlänge der Achse, sonst None)

Geändert: `system/pi/gps_measurement.py`
- Imports: `from geometry import vehicle_axis, lateral_offset_a, diff_vector_b`
- Neue globale Variablen: `current_vibration_rover3`, `quality_rover3`, `R3_angular_velocity`
- Live-Server-Variablen: `R1_lateral_offset_cm`, `R2_lateral_offset_cm`, `vehicle_axis_length_m`, `vehicle_heading_via_r3`
- Rover3-Buffers analog R1/R2 (vibration_buffer, heading_buffers, rel_heading_buffer, etc.)
- `last_relNED_r1/r2/r3` — Snapshots der jeweils letzten relPosNED (Tuple), vom Rover-Thread gesetzt, vom Logger gelesen. Python-GIL macht atomare Tuple-Assignment thread-safe.
- Rover1_Thread + Rover2_Thread: ein-Zeile-Patch, Snapshot in `last_relNED_rN` setzen
- `Rover3_Thread()` neu, voll spiegelbildlich zu Rover2_Thread (für CSV-Konsistenz; alle Werte loggable)
- `csv_logger_thread_buffered()` komplett neu:
  - 3-Wege-Sync: alle drei Rover-iTOWs müssen innerhalb `tolerance_rover = 0.1` liegen, Base innerhalb `tolerance_base = 0.5` vom Rover-Mittel
  - Var. A: Projektion R1/R2 auf Längsachse → lateral_cm, longitudinal_cm
  - Var. B: Direkte Differenzvektoren R3→R1 und R3→R2 → distance_cm, heading_deg
  - Gestängebewegungs-Indikator: `lat_r1 - lat_r2` (≈ Querbewegung des gesamten Gestänges)
  - Fallback: bei zu kurzer R3-Achse alle Var. A Werte = None (CSV: leere Zelle)
- `export_to_csv()` Header: 28 neue Spalten (17 R3 + 11 Calc), insgesamt jetzt 70 Spalten
- `start_measurement()`: ROVER3_COM_PORT einlesen, streamRover3 öffnen, Rover3_Thread starten
- `stop_measurement()`: streamRover3.close() ergänzt
- `start_measurement()` Config-Pfad korrigiert: `'..', 'config.json'` → `'..', 'config', 'config.json'` (neue Ordnerstruktur nach Reset)

`system/config/config.example.json`:
- Neues Feld `ROVER3_COM_PORT` als Template

**Warum:**

- Bisheriges Verfahren: Base-Heading aus Eigenbewegung (`base_calc_heading_buffer`) ist verrauscht und fällt im Stillstand komplett aus → bisher Notfall-Glättung über Moving-Average.
- Neues Verfahren: Vektor Base→R3 ist eine harte geometrische Achse, **auch im Stillstand stabil**. R1/R2 werden senkrecht darauf projiziert → echte Querauslenkung in Metern. Der Moving-Average bleibt als Glättung, ist aber nicht mehr für die Mittellinien-Stabilisierung nötig.
- Variante A (Projektion) ist die Hauptmetrik; Variante B (Differenzvektoren) wird parallel mitgeloggt zur Validierung und für ggf. spätere Auswertungen.

**Test offen:**

- Bench-Test am Schreibtisch mit angeschlossenen F9P-Modulen: Lassen sich alle 3 Rover öffnen, schreibt der Logger CSV-Zeilen mit 70 Spalten, sind die Werte plausibel (R1 lateral ≈ Gestängearm-Länge mit gewünschtem Vorzeichen, longitudinal ≈ 0)?
- Konvention prüfen: ist R1 in deinem Setup wirklich links (positiv) und R2 rechts (negativ)? Falls vertauscht: COM-Port-IDs in config.json tauschen.
- Hardware-Verkabelung Rover 3 mit Base (Moving-Base UART-Brücke / RTCM): erhält Rover 3 RTCM-Korrekturen wie R1/R2?
- Feldtest am Wochenende 14.-17.05.: Erste Fahrt → CSV inspizieren → Auslenkungs-Werte gegen optische / Seilzug-Referenz vergleichen.

**Risiko:**

- Vorzeichen-Konvention links/rechts: getestet in geometry.py mit 4 Test-Szenarien (heading 0°, 90°, 45°, zu-kurze-Achse). Bei Test stimmt links=positiv, rechts=negativ. **Wichtig**: bei der Montage muss R1 wirklich an die linke Auslegerseite, R2 an die rechte, R3 nach vorne in Fahrtrichtung. Bei Vertauschung sind die Vorzeichen falsch herum.
- Logger 3-Wege-Sync: falls einer der Rover länger als ~100 ms hängt, fallen Samples raus. Bei 10 Hz Sampling ist das aber ok; nur bei massiven RTK-Drops könnte Datenrate sinken.
- Globale relNED-Snapshots: bei sehr seltenen Race-Conditions könnte der Logger eine "alte" R1-Position mit einer "neuen" R3-Achse mischen. Praktisch unbedeutend bei 10 Hz, aber technisch nicht 100% race-frei. Falls Bedarf später: durch Queue mit (iTOW, relNED) ersetzen und im Logger nach passendem iTOW suchen.

---

Format pro Eintrag:
- **Datum** + Kurz-Subject
- **Was:** Konkrete Änderung mit Pfaden
- **Warum:** Begründung / Hintergrund
- **Test offen:** Was muss am System verifiziert werden
- **Risiko:** Potenzielle Probleme

---

## 2026-05-11 — Repository neu strukturiert, sauberer Schnitt

**Was:**
- Altes Repo `FJW00/MotionPSM` umbenannt zu `FJW00/MotionPSM_Old` (auf GitHub) — bleibt als Referenz erhalten.
- Neues leeres `FJW00/MotionPSM` als Zielrepo angelegt.
- Lokaler Projekt-Ordner `FJW_Schwingung` komplett reorganisiert.
- Vorher (alter Stand): software/, hardware/, documentation/, Validierung/, AS_Digi/, Abgabe/, Kalkulationen/, exist Gründungsförderung/, NDA-PDFs, alle gemischt im Repo.
- Nachher: Strikte Trennung Code+Hardware (im neuen Repo) vs. Business+Daten+BA-Doku (nur lokal+NAS, niemals Git).

**Warum:**
- Alter Repo-Stand mischte technisches Material mit NDA, Preiskalkulation, Förderanträgen und der BA-Endabgabe. Bei einer späteren Einladung von Co-Foundern / Mitarbeitern / Reviewern wäre das problematisch.
- Saubere Trennung von Anfang an erspart spätere History-Bereinigung mit `git filter-repo` (sensible Daten bleiben nach `git rm` in der History und sind über alte Commit-Hashes wieder zugänglich).
- Repo wird durch CSV-Exclusion deutlich kleiner und schneller zu klonen.

**Neue Ordnerstruktur lokal (`FJW_Schwingung/`):**
- `MotionPSM_repo/` — Git-Repo (Klon von github.com/FJW00/MotionPSM)
  - `system/` — Lebender Code, Configs, Analysis-Templates
  - `hardware/` — STEP/SLDPRT-Modelle
  - `documentation/` — DEVLOG + Auftaktnotizen
  - `archive/legacy_software/` — alte Code-Varianten als Referenz
- `business/` — Branding, Gründung, Finanzen, Recht, Kunden, Vorlagen, Website (vertraulich)
- `data/` — Messdaten-CSVs, Validierungs-Excels, Literatur-PDFs (zu groß für Repo)
- `BA_Abgabe/` — Bachelorarbeit-Endstand, eingefroren read-only
- `archive/2026-05-11_full_backup/` — 1:1 Backup des Zustands vor der Umstrukturierung
- `archive/_legacy_empty/` — geparkte, jetzt leere Original-Ordner (macOS-Sandbox erlaubt kein `rmdir`)

**Lebende Code-Variante:**
- Quelle war `software/final/BA_Weigand_Software/`
- Ziel ist jetzt `MotionPSM_repo/system/pi/`
- Files: `gps_measurement.py`, `server.py`, `autostart_schwingung_fw.sh`
- `config.json` (mit echten COM-Port-IDs) liegt unter `system/config/config.json` und ist via `.gitignore` ausgeschlossen.
- Template ohne sensible Daten: `system/config/config.example.json`

**Test offen:**
- Verifikation, dass `git clone` auf dem Raspberry Pi den Repo-Stand vom 11.05. korrekt zieht.
- Am Pi muss `config.json` aus `config.example.json` neu erstellt und mit den lokalen COM-Port-IDs befüllt werden.
- Erster `python3 system/pi/server.py`-Lauf am Pi nach dem Pull.

**Risiko:**
- Keine direkten Code-Risiken — Code-Inhalt ist 1:1 erhalten, nur Pfade haben sich geändert.
- Operativ: COM-Port-IDs in `config.json` müssen am Pi neu eingetragen werden (waren bewusst nicht im Repo).
- Falls Pfad-Hardcodes im Code stecken (z.B. relative Pfade zu Logging-Verzeichnissen), könnten die nach der Reorganisation brechen — beim ersten Pi-Lauf überprüfen.

---

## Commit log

2026-05-11 Initial commit: Repository neu strukturiert nach Reset
    - Lebender Code aus software/final/BA_Weigand_Software/ -> system/pi/
    - u-center Configs -> system/config/f9p_ucenter/
    - STEP-Modelle -> hardware/
    - Alte Code-Varianten -> archive/legacy_software/
    - Business-, Daten-, BA-Files getrennt nach lokal (nicht im Repo)
    - Sensitive Sachen (echte COM-Port-IDs, NDAs, Preise) niemals committed
    Detailed change log: documentation/DEVLOG.md
    [ANN-MB_holder.SLDPRT, ANN-MB_holder.STEP, ANN-MB_holder_v2.SLDPRT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]
2026-05-11 Rover3-Erweiterung: Längsachse Base->R3 + Mittelachsen-Projektion
    Neuer Branch fuer den 3. Rover vorne in Fahrtrichtung. Vektor Base->R3
    definiert die Laengsachse der Maschine. R1/R2 werden senkrecht darauf
    projiziert (Variante A, links=positiv) und direkt als Differenzvektor
    R3->R1/R2 (Variante B) berechnet — beides parallel ins CSV geloggt.
    Neue Files:
    - system/pi/geometry.py: vehicle_axis, lateral_offset_a, diff_vector_b
    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
2026-05-11 Visualisierung: Gestänge-Hero + 3-Rover-Quality + PROJECT_CONTEXT
    server.py komplett neu strukturiert:
    - Hero-Block: SVG-Gestaenge mit Live-Markern fuer R1/R2/R3,
    Eingabefeld Gestaengebreite (cm), drei Werte-Boxen
    - Quality-Grid pro Rover (Fix, Angular Velocity, Schwingung)
    - Achse-Info: Base->R3 Laenge + Heading + Speed
    - Zwei Charts: lateral_offset Verlauf (cm) + Heading mov_avg (deg)
    - /data Endpoint auf 16 Felder erweitert, alle JSON-safe
    - Responsive Layout (CSS Grid, mobile fallback)
    documentation/PROJECT_CONTEXT.md neu:
    - Cold-Start-Briefing fuer neue Cowork-Sessions
    - Hardware-Setup, Mess-Konzept, Repo-Struktur, Termine, Konventionen
    DEVLOG.md: zwei neue Eintraege (Visualisierun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
2026-05-13 UI: FJW-Logo + Roboto + komplett Englisch + R3 transparent + Plot weg
    server.py umfangreich ueberarbeitet nach Falks Frontend-Review:
    - Brand-Header: Logo (system/pi/static/logo_fjw.png) links + 'FJW Systems' rechts
    passend zur Briefvorlage (Roboto-Schriftart, Markenfarbe #4d4d4d)
    - Komplett Englisch: Titel, Hero-Header, Werte-Boxen, Labels
    - Groessere Schriften: H1 32px, H2 (Hero) 22px, Untertitel 16px
    - Heading-Schwingung-Plot entfernt (nur Deflection-History bleibt)
    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
2026-05-14 UI-Iteration 2: richtiges Logo (FJW_Final.png), Header-Layout, Boom-Width persistent
    - Logo: Logo_FJW_Final.png statt withoutBackround
    - Brand-Header: 'Real Time Monitor' rechts oben, gleiche Schriftgroesse
    wie 'FJW Systems' links. h1+subtitle Center-Block entfernt.
    - Settings-Bar: Boom-Width-Input ist jetzt immer sichtbar (auch wenn
    Messung gestoppt). Wert wird in localStorage gespeichert
    (Key: motionpsm_boom_width_cm) und ueber Reload/Start/Stop hinweg
    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
2026-05-14 UI-Refactor: longitudinal als Schwingungs-Hauptmetrik
    - gps_measurement: neue Module-Globals R1/R2_longitudinal_offset_cm
    (vom Logger gepflegt; + = nach vorne in Fahrtrichtung)
    - /data: 6 neue Felder (r1/r2_longitudinal_cm, symmetric/asymmetric_yaw_cm,
    r1/r2_angle_deg)
    - Frontend Hero komplett umgebaut: longitudinal als Hauptmetrik,
    Symmetric/Asymmetric Yaw nach GeoGebra-Konvention
    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
2026-05-15 Bug-Fix: relPosN/E/D Skalierung — Faktor 100 zu groß
    Die u-blox NAV-RELPOSNED Werte kommen aus pyubx2 als raw integers:
    - relPosN/E/D: in cm (nicht in Meter)
    - relPosHPN/E/D: in 0.1 mm (High-Precision-Korrektur)
    Der alte Code hat die cm-Werte als Meter behandelt, dann im Logger
    nochmal × 100 fuer cm-Anzeige → Werte um Faktor 100 zu gross.
    Aus dem Frontend wurde 'Detected Boom Width' = lat_diff_cm / 100 → m
    angezeigt, was wie Faktor 10 wirkte.
    Fix: Konvertierung in den drei Rover-Threads:
    Rover_N = (relPosN_cm + HPN * 0.01_cm) * 0.01 → m
    analog Rover_E, Rover_D
    Verifikation mit Falks CSV Records_F9P_20260515_123745.csv:
    - Rover_1_N war 475.58 (cm fehlinterpretiert), ist jetz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
2026-05-16 Filter-Iteration: 0.2s Moving-Avg via config.json + UI-Toggle Smoothed/Raw
    config.example.json:
    - Neues Feld FILTER_WINDOW_S (Default 0.2 s)
    gps_measurement.py:
    - Module-Globals R1/R2_longitudinal_filtered_cm
    - Filter-Buffer (deque) wird in start_measurement() basierend auf
    FILTER_WINDOW_S aus config.json initialisiert (0.2 s × 10 Hz = 2 Samples)
    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
2026-05-16 Tare/Zero: Set Zero Button + CSV-Spalten + REST-Endpoints
    UI:
    - Button 'Set Zero' (dezent, ⌖-Icon) links neben Smoothed/Raw-Toggle
    - Status-Anzeige 'Tared HH:MM:SS' nur sichtbar wenn tariert
    - '×'-Button zum Clear daneben
    - Tare-Status wird bei jedem /data-Fetch synchron gehalten
    Backend:
    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
2026-05-17 DEVLOG + PROJECT_CONTEXT: Nachpflegung 11.-17.05.
    DEVLOG.md ergaenzt um 7 neue Eintraege:
    - Hardware-Erkenntnis: Base muss am Schlepper, nicht am Gestaenge
    - Mathematik-Beweis: Variante A ist rotationsinvariant
    - Tare-Funktion (Set Zero / Clear)
    - Filter-Iteration: Moving-Average + UI-Toggle
    - Bug-Fix: relPosN/E/D Skalierung (Faktor 100)
    - UI-Iteration: longitudinal als Hauptmetrik + Branding
    - Autostart + Pi-Setup-Pipeline
    PROJECT_CONTEXT.md aktualisiert:
    - Hardware-Regel: Base + R3 am Schlepper (NICHT am Gestaenge)
    - Antennenhalter Eigenkonstruktion mit Kamera-Rohrklemmen
    - CSV-Layout 81 Spalten (statt 70)
    - Hauptmetriken-Block mit longitudinal als Schwingungs-Metrik
    - UI-Funktionen: Tare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
2026-05-20 Tare-Konzept-Fix + Apostroph-Bug-Fix
    Tare:
    - Lateral wird NICHT mehr tariert (war konzeptionell falsch: hat die Hebelarm-
    Laenge weggedraengt). Tare gilt jetzt nur fuer longitudinal — kompensiert
    Montage-Asymmetrie in Fahrtrichtung, geometrische Position bleibt erhalten.
    - TARE_R1_LAT_CM und TARE_R2_LAT_CM aus Module-Globals entfernt
    - set_tare() speichert nur longitudinal
    - server.py /data subtrahiert nur longitudinal-Offset, lateral bleibt unveraendert
    - 5 Tare-CSV-Spalten entfernt (R1/R2_longitudinal/lateral_tared + Tare_set_at) —
    CSV-Schlankheit: 81 -> 76 Spalten
    Apostroph-Bug:
    - Neue Helper-Funktion _fmt() ersetzt str() in den 4 Outline-Strings (Base, R1, R2, R3).
    - str() gib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
2026-05-20 PROJECT_CONTEXT: FJW Systems offiziell angemeldet 20.05.2026
    Bayern-Serviceportal, Einzelunternehmen ohne HR-Eintragung, Regelbesteuerung.
    Finale Taetigkeitsbeschreibung (breit gefaechert: Mess-/Sensor-/Automatisierungs-
    systeme, GNSS/RTK/IoT, Drohnen/Luftbild, KI/Embedded, Beratung, Handel) im
    Dokument fuer kuenftige Referenz (IHK, Foerderantraege, Investor-Pitch).
2026-05-21 PROJECT_CONTEXT: Fortschritts-Tabelle mit Status-Spalte + neue Meilensteine
    - Status-Spalte ergaenzt (✅ erledigt, ⏳ offen, herabgestuft, später)
    - Steuerberater 19.05. und Gewerbeanmeldung 20.05. eingetragen
    - Testfahrt 22./23.05. und Generalprobe 24./25.05. (vorgezogen aus 06./07.06.)
    - 06./07.06. zu Reserve-WE herabgestuft
    - Hardware-, Website- und Geschaeftskonto-Vorbereitungspunkte vor DLG
    - Nach-DLG-Aufgaben (Hardware-Aufruestung, RTCM, Cloudflare, Onepager)
2026-05-22 Logger-Sleep-Fix: time.sleep(0.1) -> 0.02 für echte 10 Hz CSV-Rate
    Befund Testfahrt 22.05.2026: CSV zeigte iTOW-Abstände von 200 ms statt 100 ms (= 5 Hz statt 10 Hz). U-blox-Configs alle korrekt auf 10 Hz, RTK Fix=4 durchgehend.
    Root Cause: csv_logger_thread_buffered() zykliert mit 100 ms Sleep + ~50 ms Verarbeitung = 150-200 ms Zyklus, drosselt effektive Sample-Rate auf ~5-7 Hz.
    Fix: time.sleep(0.1) -> 0.02 (Zeile 724). Logger zykliert jetzt mit 50 Hz, deckt 10 Hz Sampling souveraen ab, Queues bleiben leer.
    Bewusst nicht: Sync-Logik (4 separate Queues) hat latente Race-Risiken. Strukturell besser waere iTOW-Dictionary - aber das ist 50-Zeilen-Refactor, kommt post-DLG.
    Test offen: Benc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
2026-05-30 USB-only Configs v2 + 5-Hz-Fix DEVLOG
    Befund: ZED-F9P-Rover liefern nur 5 Hz NAV-RELPOSNED statt 10 Hz, obwohl
    CFG-RATE-MEAS = 100 ms ist. Ursache: NMEA-Multicast über alle 5 Ports
    (I2C+UART1+UART2+USB+SPI) drosselt Modul intern.
    Lösung: Configs mit nur USB-Output für UBX/NMEA. RTCM-Settings unangetastet,
    damit Moving-Base-UART2-Output erhalten bleibt. Item-IDs aus pyubx2-DB
    (UBX_CONFIG_DATABASE) statt geschätzt — fehlerhafte v1-Configs (off-by-one
    bei NAV-RELPOSNED USB 0x90 vs 0x8F) sind NICHT im Repo.
    Verifikation: pyubx2-Hz-Test zeigt 10.0 Hz auf allen Modulen. Hof-Test
    zeigt 10 cm + 20 cm Tare-Auslenkungen exakt.
    Verbleibendes Problem (separater Branch): Logger droppt noch 38% d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
    [Falk_weigand_config_Base_USBonly_v2.txt, Falk_weigand_config_Rover1_USBonly_v2.txt, Falk_weigand_config_Rover2_USBonly_v2.txt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]
2026-05-30 Refactor C: Logger auf iTOW-Dict statt 4 unsync'd Queues
    Hauptproblem: nach USB-only-Configs-Fix kommen Module mit 10 Hz, aber Logger
    droppt 38% der Samples wegen Race in queue.clear()+put()-Pattern. Effektive
    CSV-Rate 5.29 Hz statt 10 Hz (Stand 30.05. Hof-Test).
    Architektur-Umbau:
    - Globals: 8 queue.Queue() -> samples_by_itow dict + samples_lock
    - add_sample(itow, source, payload) Helper
    - Producer (Base/R1/R2/R3): queue.clear+put -> add_sample bei NAV-PVT/RELPOSNED
    - Consumer csv_logger_thread_buffered: poll-Sync-Toleranz -> Dict-Konsumption mit
    Komplettheits-Check (4 Sources) + SAMPLE_MAX_AGE_MS Drop-Threshold (300ms)
    - CSV-Build außerhalb des Locks (verhindert Lock-Contention)
    Produ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
2026-05-30 PROJECT_CONTEXT: Stand 30.05. — Pi 5, USB-only Configs v2, Refactor C, Website live, Termine aktualisiert
    Größere Doku-Sync nach den 5-Hz-Fix-, Hof-Test-, Refactor-C- und Website-Meilensteinen vom 30.05.
    - Stand-Datum: 2026-05-11 -> 2026-05-30
    - Hardware: Pi 4 -> Pi 5 (8 GB) seit Ende 2025, Active Cooler + neue ASA-Box
    - Base-Platzierung erweitert: Schlepperdach ODER Spritzen-Chassis (beide validiert)
    - Branches: main = 54d1dd4 Production, refactor/logger-itow-dict = Test, feature/rover3 gelöscht
    - Termine-Tabelle: alle Mai-Meilensteine als erledigt markiert, neue für Juni
    - Website fjw-systems.de LIVE inkl. Impressum + Datenschutz
    - Tech-Stack: 10 Hz auf USB durch Config-Fix + Refact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
2026-05-31 Refactor C: SAMPLE_MAX_AGE_MS 300 -> 500 ms
    Bench-Test 31.05. zeigte saubere iTOW-Sync, aber 39% Slot-Drops weil
    Module sporadisch 1 Sample skippen (0.9^4 = 65% Komplettheits-Quote).
    Mit 500ms Drop-Threshold wartet Logger laenger auf spaete Samples.
    Erwartung >90% bei 100ms.
    Pi-Buffer-Last marginal (10 statt 6 Samples max im Dict).
2026-05-31 Rollback: SAMPLE_MAX_AGE_MS 500 -> 300
    Hof-Test 14:00 zeigte mit MAX=500 nur 200ms-Steps in CSV (3.49Hz eff.) trotz
    sauberer 10Hz pro Modul auf USB. Vormittag-Test mit MAX=300 hatte 60.8% bei
    100ms erreicht - deutlich besser.
    Rollback auf bewaehrten Stand. break-Statement bleibt drin (unveraendert
    gegenueber a0fb3f3). Weitere Optimierungen kommen auf separatem Branch
    experiment/ubxreader-cleanup.
2026-06-01 Drop-Debug: print zeigt welche Source bei verworfenem iTOW fehlte
    [Logger] dropped N iTOW(s) >300ms. Fehlend: {'r3': 12, 'base': 2}
    Pure Diagnose. Zeigt direkt im Konsolen-Output welche Producer-Source
    beim Drop nicht geliefert hat -> isoliert das Bug-Modul.
2026-06-01 Lean Producer: schwere Berechnungen aus BaseThread + Rover1/2/3 raus
    Drop-Debug-Output (31.05. Hof-Tests, Browser zu) zeigt 80% der Drops:
    alle 3 Rover gleichzeitig fehlen. Klar GIL-Contention zwischen den
    Producer-Threads.
    Heavy Berechnungen RAUS:
    - BaseThread: geodesic + Point + sin/cos-Heading-Mittelwert
    - Rover1/2/3: np.linalg.lstsq (angular_velocity), mov_avg_heading
    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
2026-06-01 Lean Producer: height_boom direkt aus -Rover_D*100 (cm, positiv wenn ueber Base)
    1-Zeilen-Nachtrag pro Rover-Thread nach last_relNED-Snapshot. Keine
    Last-Relevanz, GIL-Entlastung bleibt.
2026-06-01 Stop-Cleanup: Streams first close, defensive start, samples_by_itow clear in stop
    Falk hat bemerkt: frischer Server-Start liefert deutlich bessere Drop-Statistik
    als wiederholte start/stop-Zyklen. Drop-Log bestaetigt: 32 vs 128 Drop-Lines.
    Ursache: stop_measurement() schliesst Streams ZUERST nicht. join(timeout=2)
    gibt vor Producer-Threads auf (Serial-Timeout=3s). Daemon-Threads leben weiter.
    Beim naechsten start_measurement: alte + neue Threads parallel = mehr GIL.
    Fix:
    - Streams zuerst schliessen -> Producer-read() kriegt Exception -> sauberes Ende
    - Join-Timeout 4s
    - samples_by_itow + csv_data_buffer in stop clearen statt in start
    - start_measurement: defensiv vorherige Messung stoppen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
2026-06-01 HOTFIX: csv_data_buffer NICHT in stop_measurement leeren + try/except in Producer-Threads
    Regression vom Stop-Cleanup-Commit d14be68:
    - csv_data_buffer.clear() in stop_measurement gemacht den Export tot, weil
    export_to_csv() NACH dem Stop ausgefuehrt wird.
    - Producer-Threads crashen bei stop_measurement weil close() vom Stream zu
    TypeError 'NoneType' in os.read fuehrt.
    - csv_data_buffer wird nur in start_measurement geleert (vor jeder neuen Messung)
    - try/except (TypeError, OSError, Exception) um ubr.read() in allen 4 Producer.
    Wenn stop_event gesetzt: sauberer return. Sonst: Fehler loggen + continue.
    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
2026-06-01 DLG-Lock: /tmp-Cleanup nach Export + USB-Reset-Skript
    server.py /export:
    - after_this_request-Hook: nach erfolgreichem CSV-Download (200/206)
    alle /tmp/Records_F9P_*.csv aelter 30s loeschen (gerade gesendete
    Datei sicher ausgeschlossen)
    - Vermeidet RAM-Akkumulation in /tmp (tmpfs)
    tools/usb_reset_f9p.sh (neu):
    - USB-unbind+bind aller 4 F9P-Module ueber /sys/bus/usb/drivers/usb/
    - Workaround fuer den Akkumulations-Bug (140ms direkt nach Pi-Reboot
    -> 200-250ms nach 2-3 Server-Restarts). Ersetzt Pi-Reboot.
    - sudo benoetigt, Server vorher stoppen
    DEVLOG: Eintrag zur Diagnose + Hacks + dass saubere Loesung
    (Subprocess-Architektur) post-DLG kommt.
2026-06-02 Polling 100ms (validiert in 4-Run-Hoftest 02.06.)
    setInterval(fetchData, 1000) -> 100. Hofbench am 02.06. zeigte
    mit Desktop-deaktiviertem Pi und 100ms-Polling:
    Reboot1 118ms, Restart 158ms, Reboot2 150ms, Restart 138ms.
    Akkumulations-Bug stark abgeschwaecht (Run4 sogar besser als Run3).
    Desktop-Deaktivierung war der relevante Hebel.
    Hypothese 100ms-Synchronitaet: Polling-Rhythmus liegt exakt auf
    der 10Hz-Sample-Rate, Calls fallen in Sample-Luecken.
    Tag v1.0-dlg wird auf diesen Commit force-moved.
2026-06-02 Fix usb_reset_f9p.sh: KERNEL -> KERNELS (mit S, fuer Parent-Devices)
    Pi 5 udevadm zeigt fuer das tty-Device selbst KERNEL=='ttyACM0',
    aber die USB-Bus-IDs stehen unter KERNELS== (mit S, fuer
    Parent-Devices). Mein Regex matchte nur das tty, nicht die Buses.
    Mit Fix matcht das Skript jetzt 'KERNELS=="1-1"' (oder "3-2" etc.)
    korrekt und kann unbind/bind ausfuehren.
    Test am 02.06. zeigte: alle 4 Module 'USB-Bus-ID nicht ermittelbar',
    0 erfolgreich, 4 Fehler. Bug eindeutig im Regex.
2026-06-02 UI-Button 'Pi neustarten' (Tablet-friendly Reboot fuer DLG)
    server.py:
    - Endpoint POST /system_restart: stoppt laufende Messung,
    ruft subprocess.Popen(['sudo', '-n', '/sbin/reboot'])
    - Roter Button '🔄 Pi neustarten' im Brand-Header
    - JS systemRestart() mit confirm() Dialog
    tools/setup_sudoers_reboot.sh (neu):
    - Schreibt /etc/sudoers.d/motionpsm-reboot mit NOPASSWD: /sbin/reboot
    - Einmalig per 'sudo bash tools/setup_sudoers_reboot.sh' auszufuehren
    - Pruefung via visudo -c VOR Installation (kein lockout-Risiko)
    - Erlaubt EXAKT reboot, kein anderes Kommando
    DEVLOG: Eintrag mit Test-Plan.
2026-06-02 UI-Buttons Reboot + Refresh (Tablet-friendly DLG-Controls)
    - Endpoint POST /system_restart -> sudo reboot (rot, ~60s)
    - Endpoint POST /system_refresh -> tools/motionpsm_refresh.sh (orange, ~15s)
    - 2 Buttons im Brand-Header rechts neben 'Real Time Monitor'
    - JS systemRestart() + systemRefresh() mit confirm()
    tools/motionpsm_refresh.sh (neu):
    - sleep 1.5 (Flask-Response durchlassen)
    - systemctl stop motionpsm
    - usb_reset_f9p.sh
    - systemctl start motionpsm
    - Loggt nach /tmp/motionpsm_refresh.log
    tools/setup_sudoers.sh (ersetzt setup_sudoers_reboot.sh):
    - Schreibt /etc/sudoers.d/motionpsm mit NOPASSWD fuer:
    * /sbin/reboot
    * /bin/bash <repo>/tools/motionpsm_refresh.sh
    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
2026-06-02 Fix: \\n in confirm/alert (war \n -> echtes Newline in JS-String)
    Python Triple-Quoted-Strings interpretieren \n als echtes
    Newline-Zeichen (chr 10). Das hatte den JS-String ueber zwei
    Zeilen verteilt -> Syntax-Error 'invalid token at index 681:22'
    und damit das gesamte JS lahmgelegt (Set Zero, Smoothed/Raw,
    Runtime, alles weg).
    Fix: \n -> \\n in den confirm() und alert() Strings.
    Python's Parser macht aus \\n im File ein literal \n
    (Backslash + n) in der String-Variable. Der Browser-JS-Parser
    liest das dann als 2-char-escape und interpretiert es als
    Newline -> der Dialog hat sauber mehrere Zeilen.
    Verifikation via re.match: keine echten Newlines mehr in
    confirm()/alert() Strings nach Pyth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
2026-06-02 Service-Unit: NoNewPrivileges true -> false (sudo aus Server erlauben)
    Hardening-Flag verhinderte dass server.py via sudo den reboot
    oder das refresh-Skript ausfuehren kann ('no new privileges'
    Error im Service-Log).
    UI-Buttons Reboot + Refresh brauchen sudo-Eskalation; deshalb
    muss der Service-User das duerfen. Sudoers (/etc/sudoers.d/motionpsm)
    beschraenkt das auf genau 2 Befehle - bleibt sicher.
    Nach Update am Pi:
    bash system/pi/install_autostart.sh (ueberschreibt /etc/systemd/system/motionpsm.service)
    sudo systemctl daemon-reload
    sudo systemctl restart motionpsm
2026-06-02 Refresh-Bug: KillMode=process + start_new_session=True
    systemctl stop motionpsm.service hatte das vom UI gestartete
    motionpsm_refresh.sh mitgerissen (Default KillMode=control-group
    killt alle Prozesse im service-cgroup).
    Log endete bei: '[20:33:35] systemctl stop motionpsm.service ...'
    ohne dass danach usb_reset oder start lief.
    Fix-Kombination:
    1. KillMode=process in der Service-Unit -> systemctl stop killt
    nur python3, nicht die ganze cgroup
    2. subprocess.Popen(..., start_new_session=True) -> setsid +
    neue Process-Group, ueberlebt SIGHUP/cgroup-kill noch
    robuster
    Beides zusammen: motionpsm_refresh.sh ueberlebt den service-stop
    und kann anschliessend usb_reset + service-start au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
2026-06-02 UI-Politur: Filter, Header-Text, Button-Layout, neues Logo
    1. FILTER_WINDOW_S Default 0.2 -> 0.5 s
    - gps_measurement.py
    - config.example.json (+ Kommentar angepasst)
    - Falks lokales config.json muss separat auf 0.5 (sonst Fallback auf gps_measurement.py-Default)
    2. 'Real Time Monitor' -> 'MotionPSM' im Brand-Header rechts
    3. Layout-Restructure: 4 Buttons in eigener .action-bar-Zeile unter dem Header
    - Brand-Header zweizeilig (Logo + Name) wie bisher
    - .action-bar mit space-between: links Reboot+Refresh, rechts Set Zero + Smoothed/Raw
    - Neue CSS: .action-bar, .action-bar-group, .sys-btn, .sys-btn-reboot, .sys-btn-refresh
    4. Logo: logo_fjw.png -> logo_brand.svg
    - kopier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
2026-06-02 UI-Politur II: Logo gross + Schriftzug raus + Sys-Btns dezent
    Per Falks Screenshot-Feedback:
    1. Brand-Text (FJW Systems + MOTIONPSM tagline) entfernt
    - das Logo enthaelt bereits 'FJW Systems / Falk-Jakob Weigand'
    - Doppelung war redundant
    2. Brand-Logo height 56 -> 90 px (Desktop) / 44 -> 60 px (Mobile)
    3. Reboot/Refresh-Buttons 'ausgeblichen' im Stil von tare-btn:
    - Reboot: pastel rot (#fadbd8 bg, #922b21 text, #e6a8a3 border)
    - Refresh: pastel orange (#fdebd0 bg, #a04000 text, #f5cba7 border)
    - kleiner padding/font, dezenter hover
    Brand-Header jetzt clean: nur grosses Logo links, MotionPSM-Text rechts.
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2026-06-02 UI-Politur IV: MotionPSM groesser + Status oberhalb Buttons
    - .brand-right (MotionPSM Text) 28 -> 40 px (Desktop) / 22 -> 30 px (Mobile)
    - .action-bar-center jetzt flex-direction:column:
    * Status-Text oberhalb (Running 12s / Stopped)
    * Buttons (Start/Export/Stop) darunter in .meas-controls
    - .meas-btn etwas groesser: padding 5/14 -> 7/20, font 12 -> 14
    - .meas-status font 12 -> 13 px + bold + letter-spacing fuer Lesbarkeit
2026-06-02 UI-Politur V: Alle Buttons auf einer Hoehe + Feinabstimmung Sizes
    - .brand-right (MotionPSM) 40 -> 34 px (Desktop) / 30 -> 26 px (Mobile)
    - .action-bar-center wieder flex-row (column-Variante zurueckgenommen):
    Status-Text inline neben den Buttons -> alle 6 Buttons auf gleicher Hoehe
    - .meas-btn 14/7-20 -> 13/7-18 (etwas kompakter)
    - .meas-controls wrapper-div weg (nicht mehr noetig)
2026-06-02 UI: Status-Text in Brand-Header zwischen Logo und MotionPSM
    - Aus Action-Bar entfernt: <span class=meas-status> mit Running/Stopped
    - In Brand-Header eingefuegt zwischen .brand-left und .brand-right-block
    -> dank flex space-between automatisch mittig zwischen Logo und MotionPSM
    - CSS-Klasse umbenannt: .meas-status -> .brand-status, gleiche Stile
    - Action-Bar-Mitte hat jetzt nur noch Start (oder Export+Stop), keine
    Statustextanzeige mehr
    Status oben deutlich im Blick - Running gruen, Stopped rot.
2026-06-02 Fix: Mitte exakt zentriert (Grid 1fr/auto/1fr statt space-between)
    Problem: brand-status 'Stopped' stand nicht ueber dem Start-Button,
    weil brand-left (Logo+FJW-Text) und brand-right-block (MotionPSM)
    unterschiedlich breit sind. space-between zentriert die Mitte im
    FREIEN Raum, nicht im Container.
    Fix: beide Container (brand-header + action-bar) auf CSS Grid
    mit grid-template-columns: 1fr auto 1fr umgestellt. Linke und
    rechte Spalte sind jetzt gleich breit -> mittlere Spalte (Status
    bzw. Start-Button) sitzt exakt im Container-Zentrum.
    brand-left { justify-self: start }
    brand-status { justify-self: center }
    brand-right { justify-self: end }
    Stopped steht jetzt exakt ueber Star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
2026-07-26 Fix: UBXReader EINMAL pro Thread instanzieren — Bug fuer 5-Hz-Problem behoben
    Alter Code hat 'ubr = UBXReader(stream, validate=0)' in JEDER while-
    Iteration neu erzeugt (in BaseThread + Rover1/2/3_Thread). pyubx2
    verwendet einen internen Byte-Puffer der beim Neu-Erzeugen verworfen
    wird -> Partial-UBX-Frames im Stream-Buffer gehen verloren -> jede
    zweite NAV-PVT/NAV-RELPOSNED-Message verpasst -> CSV lief auf 5 Hz
    statt 10 Hz.
    Fix: ubr wird beim Thread-Start EINMAL instanziert und dann in der
    while-Schleife nur noch mit .read() aufgerufen. Reader-State bleibt
    erhalten, keine verlorenen Frames mehr.
    Ursprung: Experiment-Commit a56b95f vom 31.05.2026 auf Branch
    experiment/ubxreader-cleanup,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
2026-08-15 DEVLOG: Sample-Rate-Diagnose 05.08.-15.08. dokumentiert (RTCM3/NMEA-Fix, Akkumulations-Bug, Live-Degradation)
    Deckt die komplette Diagnose-Session ab: Base-RTCM3/NMEA-Multicast-Fix,
    Lokalisierung des Akkumulations-Bugs im F9P-Modul (nicht Pi/Kernel/Python,
    CFG-RST als Workaround), Entdeckung der Live-Degradation waehrend laufender
    Messungen (Kandidat "thermische Drosselung" ausgeschlossen), sowie Nachtrag
    der DEVLOG-Luecke Juni/Juli. Datums-Korrektur fuer Eintraege, die faelschlich
    auf 05.08. statt 14.08. datiert waren.
